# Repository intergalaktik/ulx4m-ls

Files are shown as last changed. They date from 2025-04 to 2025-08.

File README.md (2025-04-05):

<!--
SPDX-FileCopyrightText: 2016 2016 Goran Mahovlic, <goran.mahovlic@gmail.com> et al.

SPDX-License-Identifier: CERN-OHL-S-2.0
-->

# ULX4M-LS PCB

[ULX4M] = University digital Logic Learning Xtensible board release 4 Moduler successor of [ULX3S](http://radiona.org/ulx3s) = [University digital Logic](https://www.fer.unizg.hr/en/course/diglog) Learning
Xtensible board release 3 with SDRAM,
Successor of [ULX2S](http://github.com/emard/ulx2s).

### 3D preview

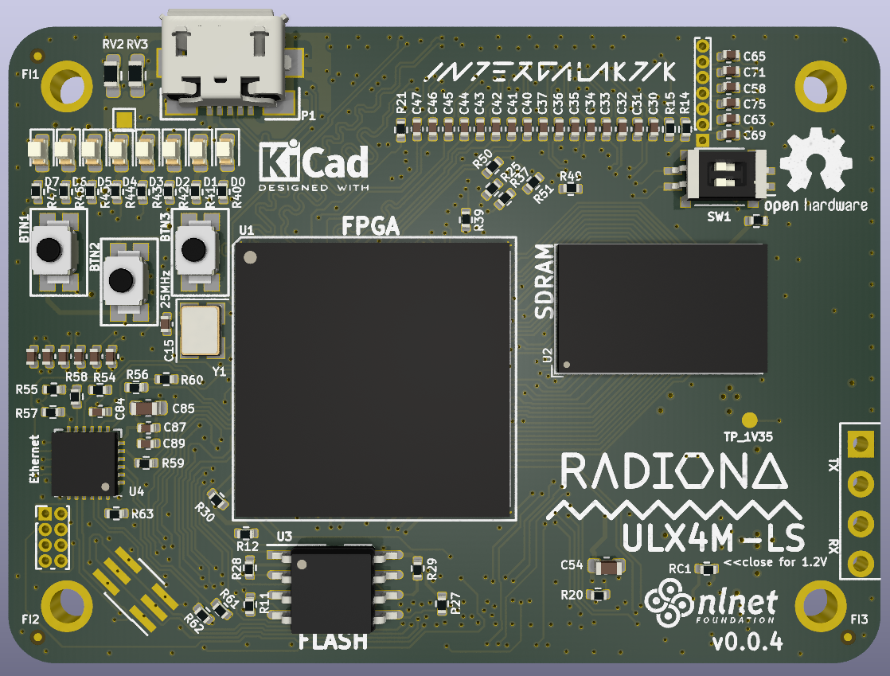
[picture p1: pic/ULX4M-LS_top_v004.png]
TOP

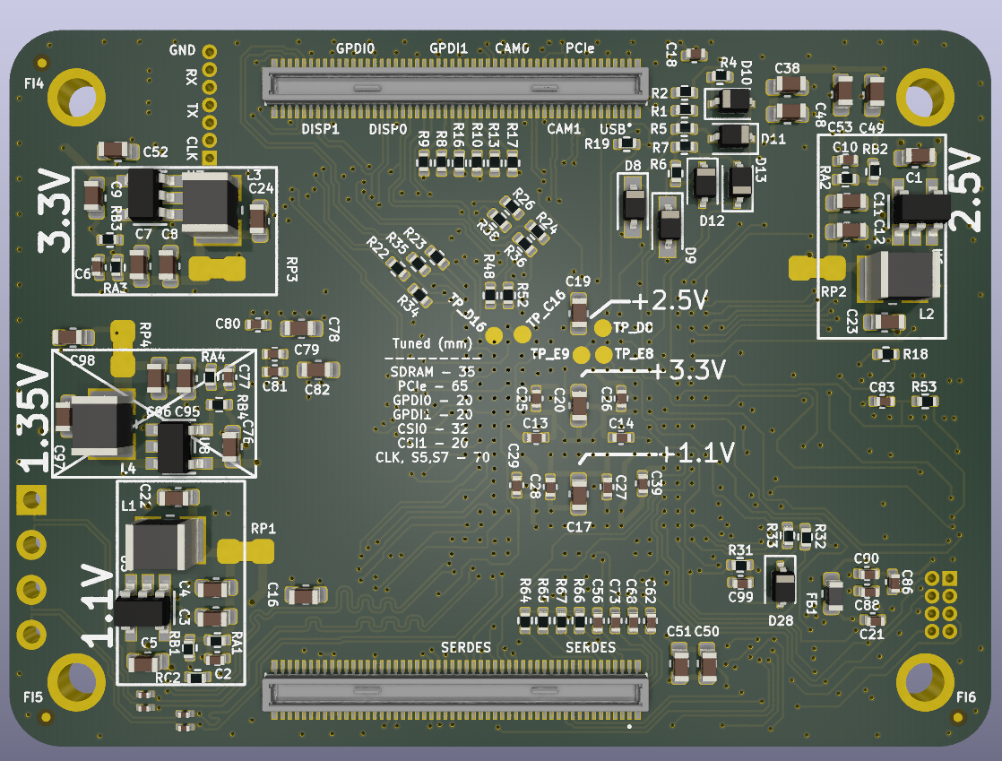
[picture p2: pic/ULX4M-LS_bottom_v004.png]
BOTTOM

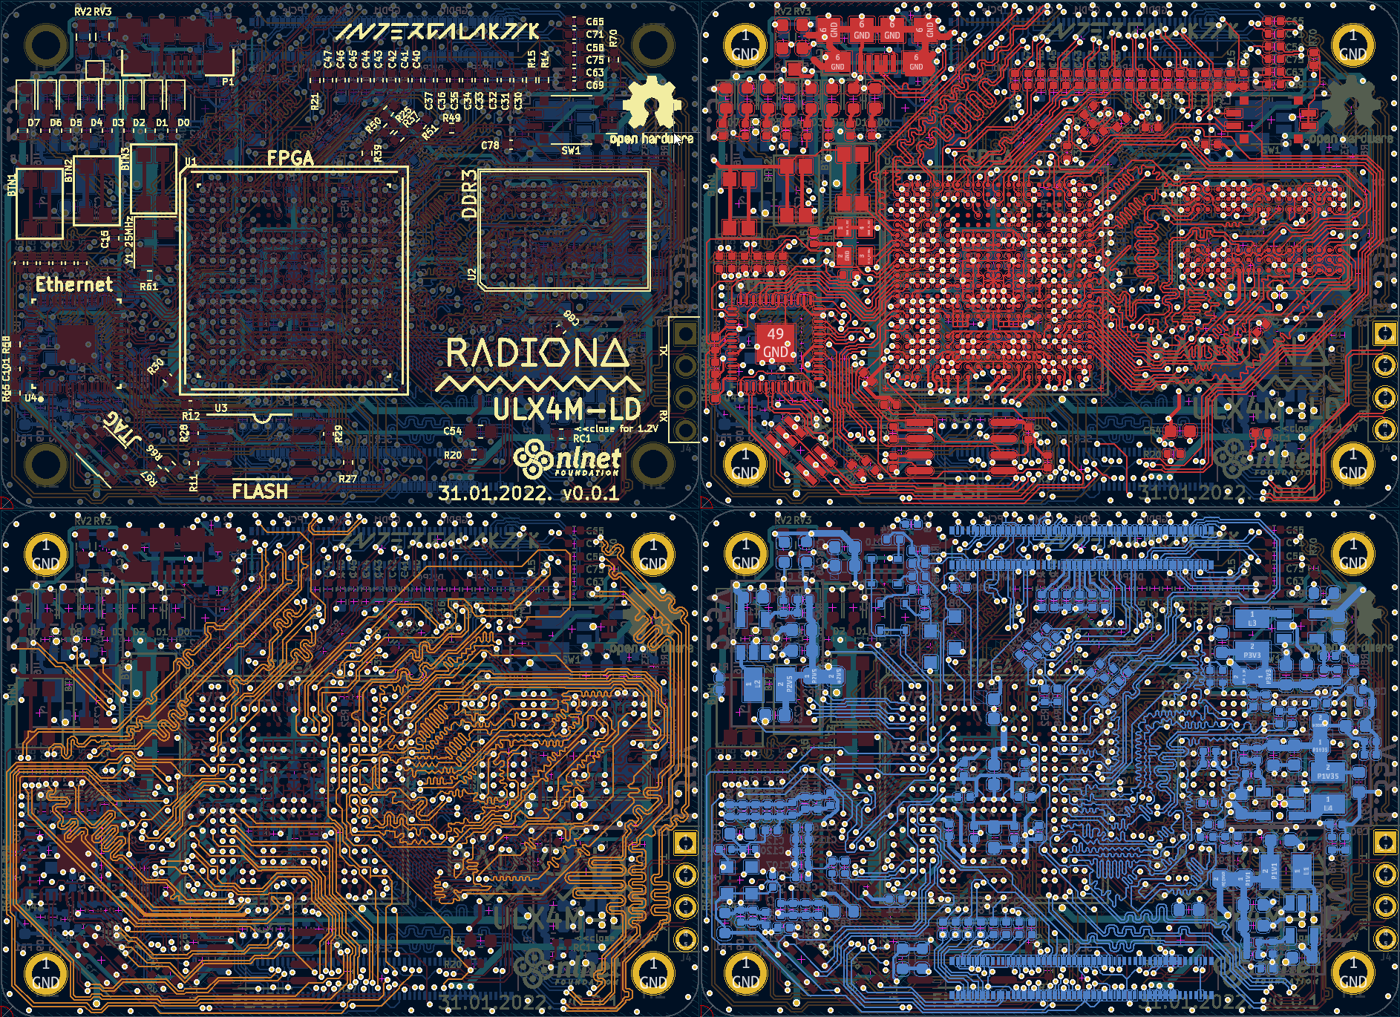
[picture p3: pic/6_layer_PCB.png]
Layers_v001


### Panel

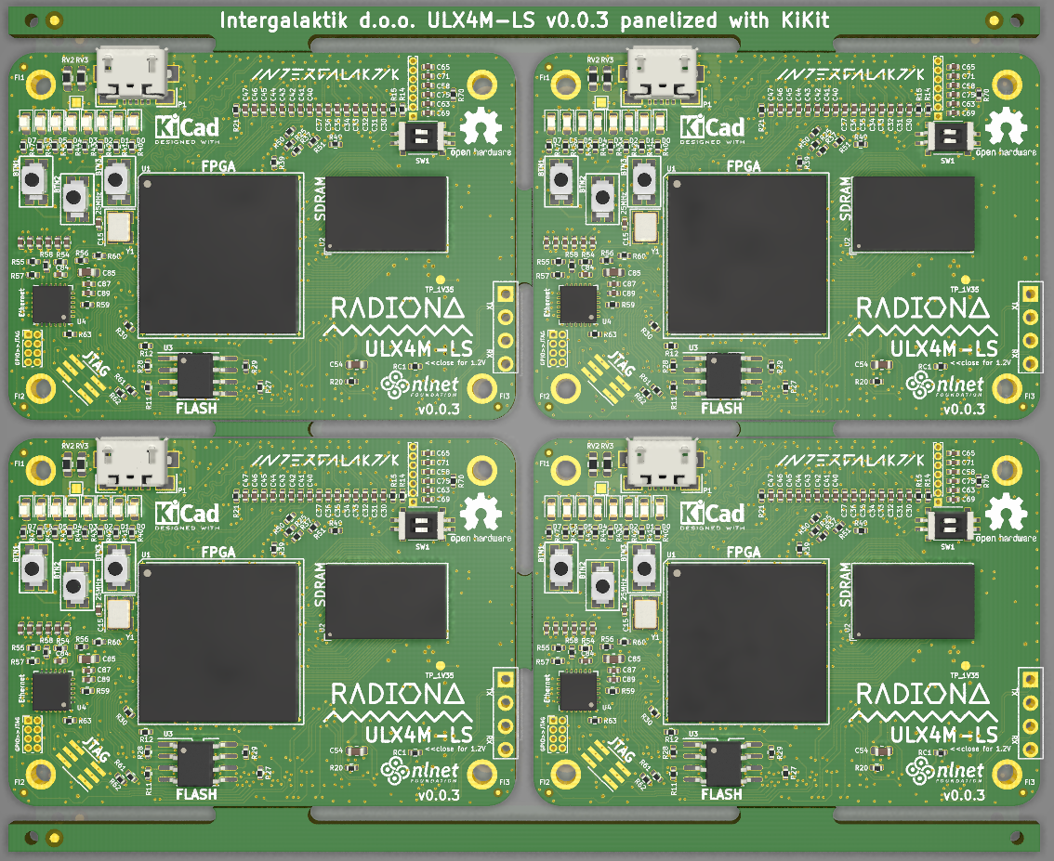
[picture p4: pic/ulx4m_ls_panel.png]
Panel


[Schematics](/doc/schematics.pdf) and PCB KiCAD 5 PCB editor:

    kicad ulx4m.pro

## Features

FPGA: Lattice ECP5 [LFE5U-12F-6BG381C](http://www.latticesemi.com/~/media/LatticeSemi/Documents/DataSheets/ECP5/FPGA-DS-02012.pdf?document_id=50461) (12/25/45/85K LUT)

### Main parts

LFE5U-12F-6BG381C

IS42S16160G-7BL 32 MB SDRAM 

W25Q128JVSIM NOR Flash spiFlash, 3V, 128M-bit, 4Kb Uniform Sector

Ethernet - LAN8720A

### Programming options

External JTAG programming connector

JTAG connected to GPIO (programming with FTDI or ESP32)

USB (bootloader)

### Periferals

- [x] 2 lane CSI camera port  CAM0 and CAM1

- [x] 2 lane DSI display port DISP0 (fake differential)

- [x] DISP0 pins connected to DISP1

- [x] * SerDes pair (TX/RX) connected to 2.0 header (radio experiments)

- [x] True differential GPDI video output

- [x] Fake differential GPDI video output

- [x] 4 bit SD card connection

- [x] * SerDes connected to PCIe 1x 

- [x] * 2x SerDes pairs connected over capacitors to connector

- [x] GPIOs

- [x] 3 Buttons

- [x] 2 DIP SW

- [x] 8 LEDs

* Only available if ECP5 SerDes chip is used

### ULX4M on TOFU carrier board

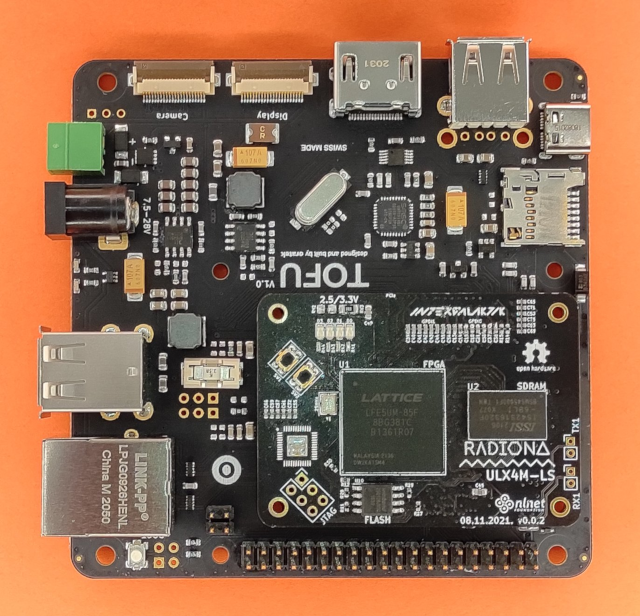
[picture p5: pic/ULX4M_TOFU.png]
TOFU


## References

https://github.com/gatecat/TrellisBoard

https://github.com/orangecrab-fpga/orangecrab-hardware

https://github.com/antmicro/ecp5-dc-scm

https://github.com/butterstick-fpga/butterstick-hardware

## Work on this board is financed by NLnet foundation

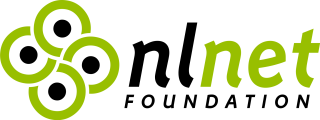
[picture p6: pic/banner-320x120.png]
NLnet


https://nlnet.nl/project/ULX3M/

## Check up our blogposts

https://intergalaktik.eu/news/ulx4s-v0-0-1

https://intergalaktik.eu/news/ulx4s-v0-0-2

https://intergalaktik.eu/news/blending-ulx4m-nlnet-funded-fpga-board

https://intergalaktik.eu/news/production-testing-automation-for-ulx3s

https://intergalaktik.eu/news/blending-ulx4m-ls-v002

## Contact us

Discord: https://discord.gg/qwMUk6W

Gitter: https://gitter.im/ulx3s/Lobby

Mail: warp@intergalaktik.eu

Twitter: https://twitter.com/intergalaktikEU

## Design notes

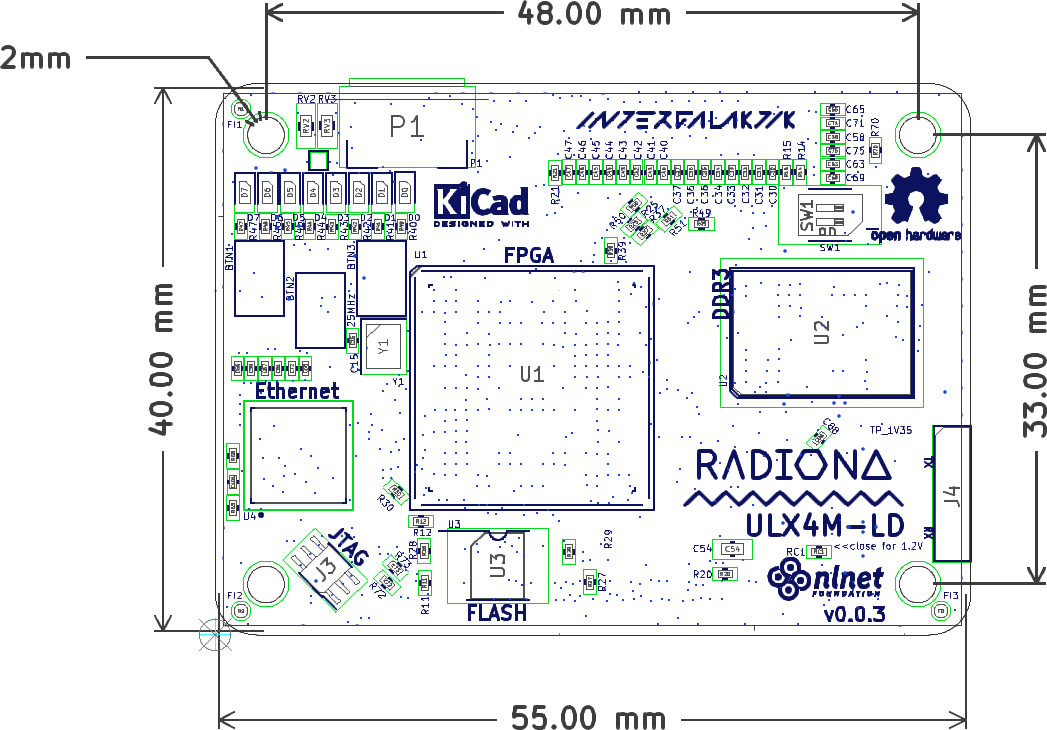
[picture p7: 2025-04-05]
pic/ulx4m_drawings.png

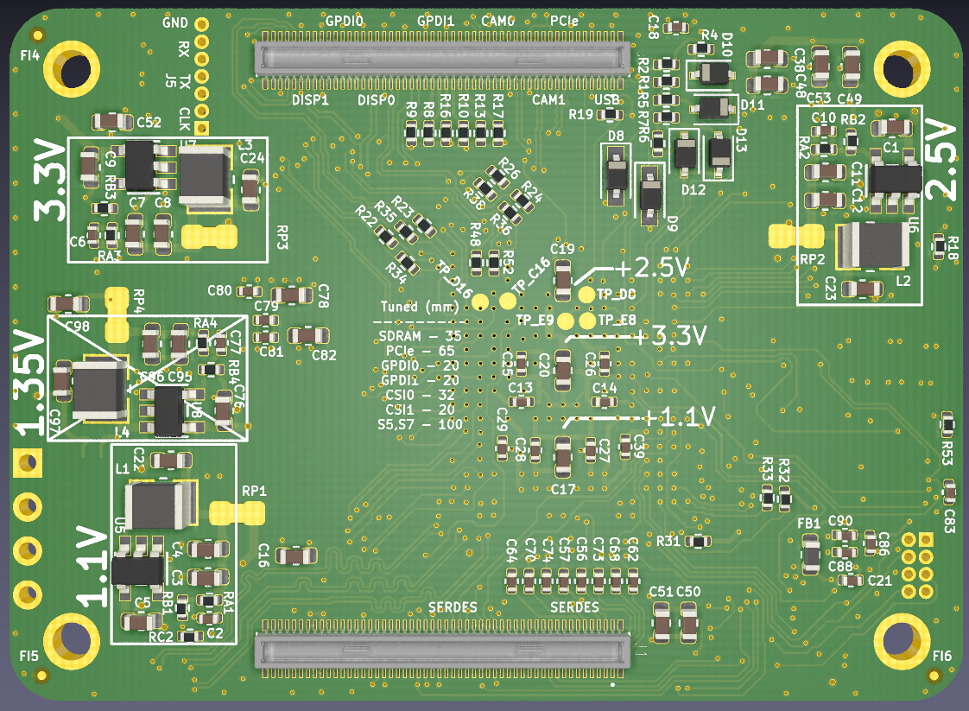
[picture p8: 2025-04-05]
pic/ULX4M-LS_bottom_v003.png

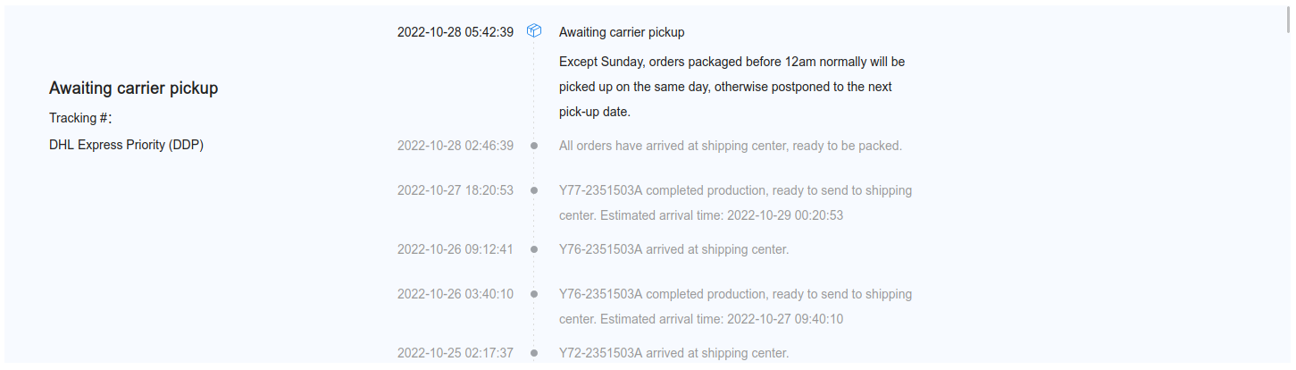
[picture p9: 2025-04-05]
pic/shipping.png

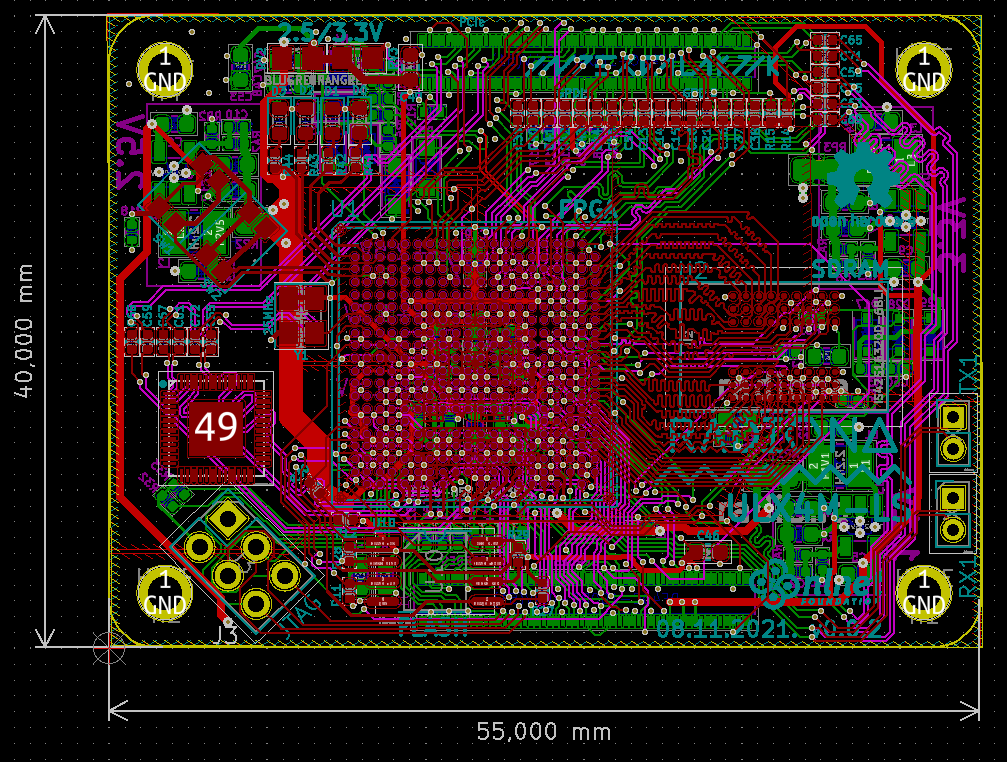
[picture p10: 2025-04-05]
pic/ULX4M_routed_V002.png

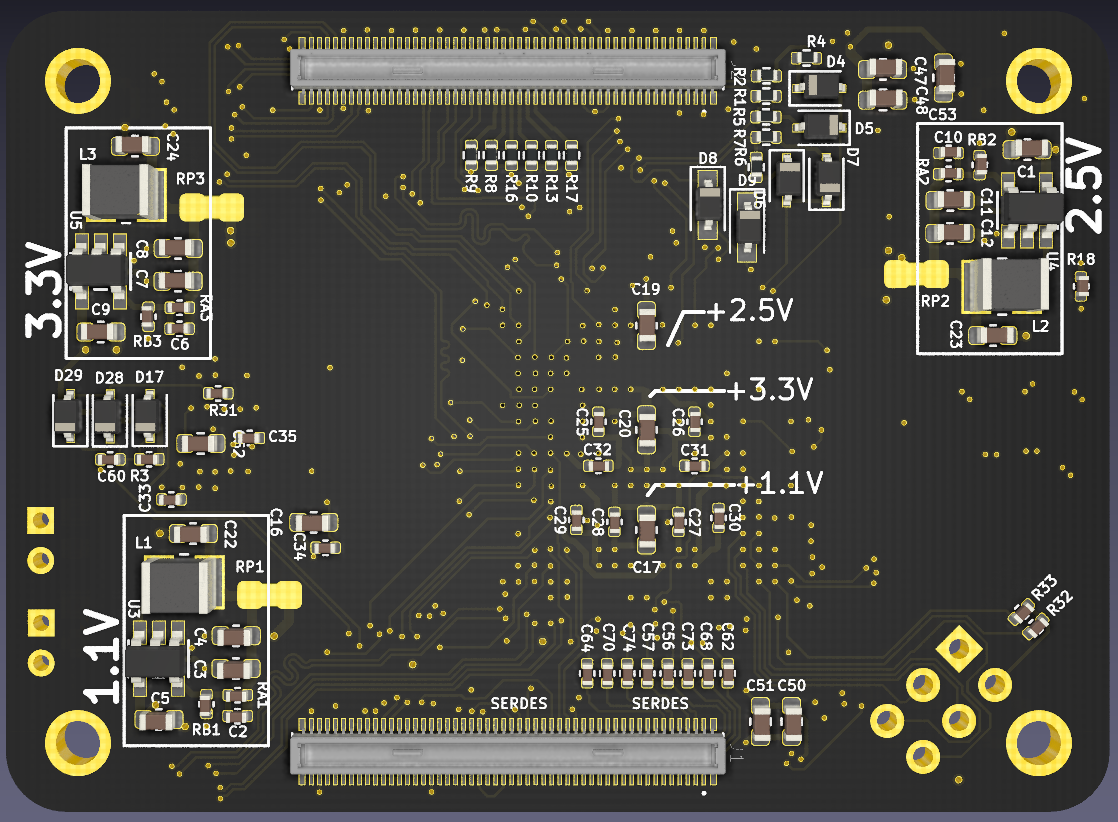
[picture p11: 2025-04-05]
pic/ULX4M_bottom_v002.png

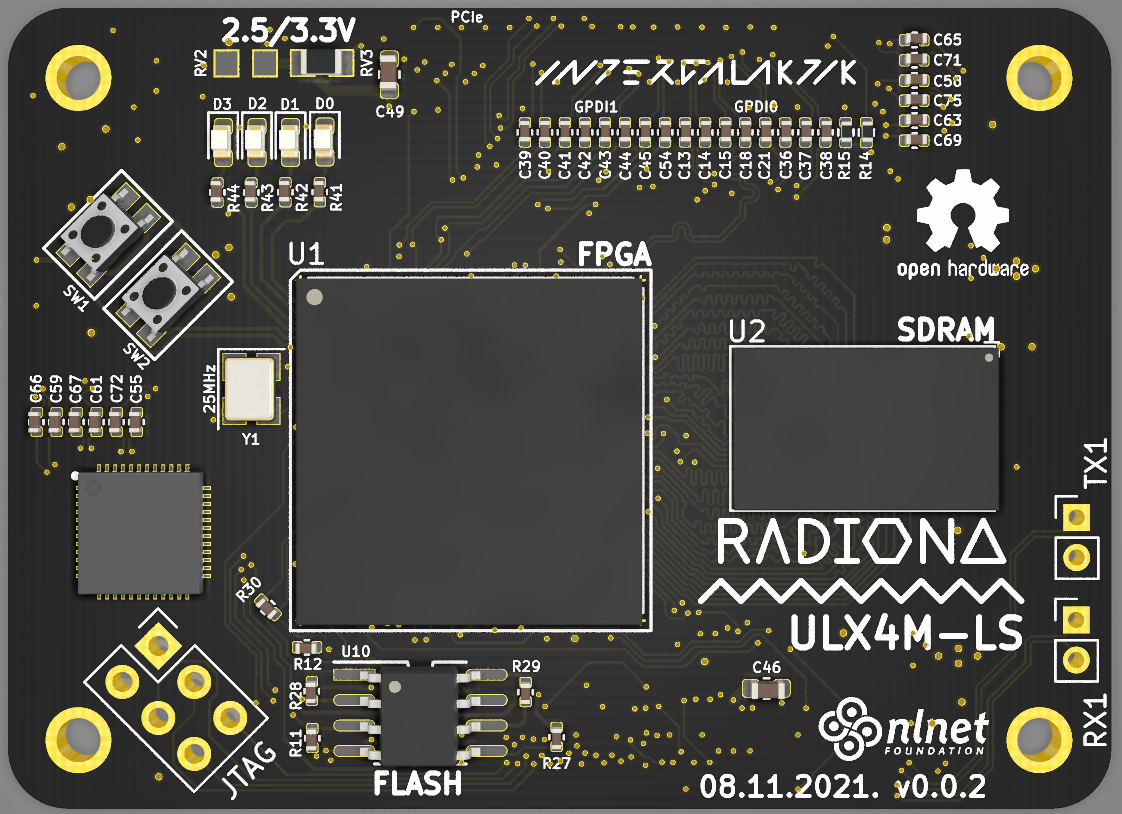
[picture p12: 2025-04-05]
pic/ULX4M_top_v002.png

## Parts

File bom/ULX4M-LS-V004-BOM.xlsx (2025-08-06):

Reference | Manufacturer Part Number | Manufacturer | Part Match | Description | Quantity | Selected Offers | Selected Offers (Distributor Link) | Packaging | Min | Mult | Total Quantity | Total Price | Selected Offers | Selected Offers (Distributor Link) | Arrow Electronics | Avnet | DigiKey | Future Electronics | Mouser | Newark | RS | Manufacturer Lifecycle | RoHS | REACH | Unit Price | Subtotal | Stock
C13, C14, C15, C18, C21, C25, C26, C27, C28, C29, C39, C55, C56, C58, C59, C61, C62, C63, C65, C66, C67, C68, C69, C71, C72, C73, C75, C79, C80, C81, C88 | GRM155R60J223KA01D | Murata | Exact | 0402 22 nF 6.3 V ±10% Tolerance X5R SMT Multilayer Ceramic Capacitor | 31 | Arrow Electronics GRM155R60J223KA01D (https://octopart.com/opatz8j6/a1) | https://octopart.com/opatz8j6/a1 | Cut Tape | 1 | 1 | 31 | 0.0403 | Arrow Electronics GRM155R60J223KA01D | https://octopart.com/opatz8j6/a1 | GRM155R60J223KA01D |  |  |  | 81-GRM155R60J223KA1D | 97AK4044 |  | Not Recommended for New Designs | Compliant | Yes | 0.00118 | 0.43701 | 369
R18, R21, R22, R23, R24, R25, R26, R34, R35, R36, R37, R38, R40, R41, R42, R43, R44, R45, R46, R47, R61, R62, R64, R65, R66, R67, R70 | AC0402JR-07300RL | Yageo | Exact | Res Thick Film 0402 300 Ohm 5% 0.063W(1/16W) ±100ppm/C Pad SMD Automotive T/R | 27 | Mouser 603-AC0402JR-07300RL (https://octopart.com/opatz8j6/a1) | https://octopart.com/opatz8j6/a1 | Tape & Reel | 1 |  | 27 | 0.189 | DigiKey YAG3540CT-ND | https://octopart.com/opatz8j6/a1 | AC0402JR-07300RL | 58AK8897 | YAG3540CT-ND |  | 603-AC0402JR-07300RL | 58AK8897 |  | Active | Compliant | Yes | 0.0047 | 9.87 | 16172
C30, C31, C32, C33, C34, C35, C36, C37, C40, C41, C42, C43, C44, C45, C46, C47, C83, C84, C90, C99 | GRM152R60J104KE19D | Murata | Exact | Ceramic Capacitor, Multilayer, Ceramic, 6.3V, 10% +Tol, 10% -Tol, X5R, 15% TC, 0.1uF, Surface Mount, 0402 | 20 | Arrow Electronics GRM152R60J104KE19D (https://octopart.com/opatz8j6/a1) | https://octopart.com/opatz8j6/a1 | Cut Tape | 1 | 1 | 20 | 0.21 | Arrow Electronics GRM152R60J104KE19D | https://octopart.com/opatz8j6/a1 | GRM152R60J104KE19D |  | 490-14871-1-ND |  | 81-GRM152R60J104KE9D |  |  | Not Recommended for New Designs | Compliant | Yes | 0.00783 | 16.45 | 41966
R5, R7, R8, R9, R11, R12, R16, R17, R27, R28, R31, R32, R33, RA1, RA2, RA3 | AC0402JR-7W15KL | Yageo | Exact | Chip Resistor Automotive Grade Thick Film 0402 15kOhm 5% Paper T/R | 16 | Mouser 603-AC0402JR-7W15KL (https://octopart.com/opatz8j6/a1) | https://octopart.com/opatz8j6/a1 | Tape & Reel | 1 |  | 16 | 0.24 | Mouser 603-AC0402JR-7W15KL | https://octopart.com/opatz8j6/a1 |  |  |  |  | 603-AC0402JR-7W15KL |  |  | Active | Compliant | Yes | 0.00729 | 12.39 | 9990
C16, C17, C19, C20, C22, C23, C24, C38, C54, C78, C85 | GRM185R60J225KE26J | Murata | Exact | Ceramic Capacitor, Multilayer, Ceramic, 6.3V, 10% +Tol, 10% -Tol, X5R, 15% TC, 2.2uF, Surface Mount, 0603 | 11 | Mouser 81-GRM185R60J225KE6J (https://octopart.com/opatz8j6/a1) | https://octopart.com/opatz8j6/a1 | Tape & Reel | 1 |  | 11 | 1.35 | DigiKey 490-6371-1-ND | https://octopart.com/opatz8j6/a1 |  |  | 490-6371-1-ND |  | 81-GRM185R60J225KE6J |  |  | Not Recommended for New Designs | Compliant | Yes | 0.03944 | 43.38 | 30510
C1, C3, C4, C5, C7, C8, C9, C11, C12 | GRM188R60J226MEA0J | Murata | Exact | 0603 6.3 V 22 uF ±20% Tolerance X5R SMT Multilayer Ceramic Chip Capacitor | 9 | Mouser 81-GRM188R60J226ME0J (https://octopart.com/opatz8j6/a1) | https://octopart.com/opatz8j6/a1 | Tape & Reel | 1 |  | 10 | 0.91 | LCSC C426040 | https://octopart.com/opatz8j6/a1 | GRM188R60J226MEA0J | GRM188R60J226MEA0J | 490-GRM188R60J226MEA0JCT-ND |  | 81-GRM188R60J226ME0J | 66AJ7192 | 2478053 | Active | Compliant | Yes | 0.0129 | 15.48 | 6180
R10, R13, R14, R15, R19, R20, R30, RB2 | AC0402JR-074K7L | Yageo | Exact | SMD Chip Resistor 4.7 Kohm ½ 5% 63 Mw 0402 [1005 Metric] Thick Film General Purpose | 8 | Avnet 49AK0473 (https://octopart.com/opatz8j6/a1) | https://octopart.com/opatz8j6/a1 |  | 1 | 1 | 8 | 0.04 | Avnet 49AK0473 | https://octopart.com/opatz8j6/a1 | AC0402JR-074K7L | 49AK0473 | 311-4.7KLBCT-ND |  | 603-AC0402JR-074K7L | 49AK0473 | 1978008 | Active | Compliant | Yes | 0.00456 | 4.56 | 8750
C48, C49, C50, C51, C52, C53, C82 | GCM188R72A223KA37J | Murata | Exact | Multilayer Ceramic Capacitor 0.022 Uf 100 V ½ 10% X7R 0603 [1608 Metric] | 7 | Arrow Electronics GCM188R72A223KA37J (https://octopart.com/opatz8j6/a1) | https://octopart.com/opatz8j6/a1 | Cut Tape | 1 | 1 | 10 | 0.079 | Arrow Electronics GCM188R72A223KA37J | https://octopart.com/opatz8j6/a1 | GCM188R72A223KA37J | GCM188R72A223KA37J | 490-17777-1-ND | 5139968 | 81-GCM188R72A223KA7J | 66AJ7159 |  | Active | Compliant | Yes | 0.00683 | 4.1 | 29893
R1, R2, R54, R56, R58, R59, R60 | AC0402JR-0727RL | Yageo | Exact | AC Series 0402 27 Ohm ±5% 0.063 W ±200 ppm/°C Thick Film Chip Resistor | 7 | Mouser 603-AC0402JR-0727RL (https://octopart.com/opatz8j6/a1) | https://octopart.com/opatz8j6/a1 | Tape & Reel | 1 |  | 10 | 0.07 | DigiKey 13-AC0402JR-0727RLCT-ND | https://octopart.com/opatz8j6/a1 |  | 58AK8894 | 13-AC0402JR-0727RLCT-ND |  | 603-AC0402JR-0727RL | 58AK8894 |  | Active | Compliant | Yes | 0.0056 | 1.12 | 52516
D10, D11, D12, D13, D15, D28 | 1N914BWS | onsemi | Exact | Diode Ultra Fast Recovery Rectifier 75V 0.15A 2-Pin SOD-323F T/R | 6 | Newark 18X9969 (https://octopart.com/opatz8j6/a1) | https://octopart.com/opatz8j6/a1 | Cut Tape | 1 | 1 | 6 | 0.138 | TME 1N914BWS | https://octopart.com/opatz8j6/a1 | 1N914BWS | 1N914BWS | 1N914BWSCT-ND | 4190584 | 512-1N914BWS | 18X9969 |  | Active | Compliant | Yes | 0.0325 | 16.25 | 2230
R39, R48, R49, R50, R51, R52 | AC0402FR-0771R5L | Yageo | Exact | Chip Resistor Automotive Grade Thick Film 0402 71.5Ohm 1% Paper T/R | 6 | Mouser 603-AC0402FR-0771R5L (https://octopart.com/opatz8j6/a1) | https://octopart.com/opatz8j6/a1 | Tape & Reel | 1 |  | 10 | 0.14 | Mouser 603-AC0402FR-0771R5L | https://octopart.com/opatz8j6/a1 |  |  | 13-AC0402FR-0771R5LCT-ND |  | 603-AC0402FR-0771R5L |  |  | Active | Compliant | Yes | 0.0082 | 6.56 | 29460
R4, R6, R29, R55, R57 | AC0402JR-7W1KL | Yageo | Exact | Res Thick Film 0402 1K Ohm 5% 0.125W(1/8W) ±100ppm/°C Pad SMD T/R Automotive AEC-Q200 | 5 | Mouser 603-AC0402JR-7W1KL (https://octopart.com/opatz8j6/a1) | https://octopart.com/opatz8j6/a1 | Tape & Reel | 1 |  | 10 | 0.09 | DigiKey 13-AC0402JR-7W1KLCT-ND | https://octopart.com/opatz8j6/a1 |  |  | 13-AC0402JR-7W1KLCT-ND |  | 603-AC0402JR-7W1KL |  |  | Active | Compliant | Yes | 0.0061 | 3.05 | 10054
L1, L2, L3 | DFE322520F-2R2M=P2 | Murata | Exact | Inductor Chip Shielded Wirewound 2.2uH 20% 1MHz Metal Alloy 3.3A 1210 Emboss T/R | 3 | 81-DFE322520F2R2M=P2 (https://octopart.com/opatz8j6/a1) | https://octopart.com/opatz8j6/a1 | Tape & Reel | 1 |  | 3
U5, U6, U7 | TLV62569DBVR | Texas Instruments | Exact | Conv DC-DC 2.5V to 5.5V Synchronous Step Down Single-Out 0.6V to 5.5V 2A 5-Pin SOT-23 T/R | 3 | Arrow Electronics TLV62569DBVR (https://octopart.com/opatz8j6/a1) | https://octopart.com/opatz8j6/a1 | Cut Tape | 1 | 1 | 3 | 0.66 | DigiKey 296-47360-1-ND | https://octopart.com/opatz8j6/a1 | TLV62569DBVR |  | 296-47360-1-ND |  | 595-TLV62569DBVR |  |  | Active | Compliant |  | 0.09528 | 38.11 | 12574
BTN1, BTN2, BTN3 | EVPAA302K | Panasonic | Exact | Switch Tactile N.O. SPST Rectangular Button J-Bend 0.02A 15VDC 1.6N SMD Embossed T/R | 3 | Mouser 667-EVP-AA302K (https://octopart.com/opatz8j6/a1) | https://octopart.com/opatz8j6/a1 | Tape & Reel | 1 |  | 3 | 2.25 | Newark 47AC4938 | https://octopart.com/opatz8j6/a1 |  |  |  |  |  | 47AC4938 |  | Active | Compliant | Yes | 0.36805 | 110.41 | 422
C2, C6, C10 | 04026C101KAT2A | KYOCERA AVX | Exact | SMD Multilayer Ceramic Capacitor, 100 pF, 6.3 V, 0402 [1005 Metric], ï¿½ 10%, X7R | 3 | Mouser 581-04026C101KAT2A (https://octopart.com/opatz8j6/a1) | https://octopart.com/opatz8j6/a1 | Tape & Reel | 1 |  | 3 | 0.63 | Mouser 581-04026C101KAT2A | https://octopart.com/opatz8j6/a1 |  | KGM05AR70J101KH |  |  | 581-04026C101KAT2A |  |  | Active | Compliant | Yes | 0.06468 | 25.87 | 25210
D0, D4 | LTST-C190KRKT | Lite-On | Exact | LED LTST-C190KRKT; SMD 0603; czerwona 631-639nm; 99mcd /20mA; water clear | 2 | DigiKey 160-1436-1-ND (https://octopart.com/opatz8j6/a1) | https://octopart.com/opatz8j6/a1 | Cut Tape | 1 |  | 2 | 0.28 | DigiKey 160-1436-1-ND | https://octopart.com/opatz8j6/a1 | LTST-C190KRKT | LTST-C190KRKT | 160-1436-1-ND | 5050042 |  |  | 6920981 | Active | Compliant | Yes | 0.05912 | 11.82 | 12041
D3, D7 | LTST-C190TBKT | Lite-On | Exact | LTST-C190TBKT Lite-on Standard Led Blue 470NM 3.3V SMD 0603 Rohs | 2 | DigiKey 160-1646-1-ND (https://octopart.com/opatz8j6/a1) | https://octopart.com/opatz8j6/a1 | Cut Tape | 1 |  | 2 | 0.68 | TME LTST-C190TBKT | https://octopart.com/opatz8j6/a1 |  |  | 160-1646-1-ND | 4438875 |  |  | 6920994 | Active | Compliant | Yes | 0.0734 | 14.68 | 18883
D1, D5 | LTST-C190KAKT | Lite-On | Exact | Single Color LED, Red Orange, Water Clear, 1.06mm | 2 | DigiKey 160-1433-1-ND (https://octopart.com/opatz8j6/a1) | https://octopart.com/opatz8j6/a1 | Cut Tape | 1 |  | 2 | 0.4 | DigiKey 160-1433-1-ND | https://octopart.com/opatz8j6/a1 | LTST-C190KAKT |  | 160-1433-1-ND |  |  |  |  | Active | Compliant | Yes | 0.125 | 25 | 47325
D2, D6 | LTST-C191KGKT | Lite-On | Exact | Single Color LED, Ultra Bright Green, Water Clear, 1.1mm | 2 | DigiKey 160-1446-1-ND (https://octopart.com/opatz8j6/a1) | https://octopart.com/opatz8j6/a1 | Cut Tape | 1 |  | 2 | 0.3 | TME LTST-C191KGKT | https://octopart.com/opatz8j6/a1 | LTST-C191KGKT |  | 160-1446-1-ND | 3023739 |  |  | 6921010 | Active | Compliant | Yes | 0.0433 | 8.66 | 6081
D8, D9 | BZT52C3V6S-TP | MCC | Exact | Zener Diode, 3.6V V(Z), 5.56%, 0.2W, Silicon, Unidirectional | 2 | Mouser 833-BZT52C3V6S-TP (https://octopart.com/opatz8j6/a1) | https://octopart.com/opatz8j6/a1 | Tape & Reel | 1 |  | 2 | 0.6 | Mouser 833-BZT52C3V6S-TP | https://octopart.com/opatz8j6/a1 | BZT52C3V6S-TP |  | BZT52C3V6S-TPMSCT-ND |  | 833-BZT52C3V6S-TP |  |  | Active | Compliant | Yes | 0.06924 | 13.85 | 1313
Y1 | ECS-2333-250-BN-TR | ECS International | Exact | Series ESC-2333 3.3V 15pF -40°C~+85°C ±50ppm SMD/SMT Standard Clock Oscillators | 2 | Mouser 520-2333-250-BNT (https://octopart.com/opatz8j6/a1) | https://octopart.com/opatz8j6/a1 | Tape & Reel | 1 |  | 2 | 1.64 | Mouser 520-2333-250-BNT | https://octopart.com/opatz8j6/a1 | ECS-2333-250-BN-TR | ECS-2333-250-BN-TR | XC3035CT-ND |  | 520-2333-250-BNT | 79AK9042 |  | Active | Compliant | Yes | 0.61857 | 123.71 | 2724
J1, J2 | DF40C-100DP-0.4V(51) | HIROSE ELECTRIC | Exact | Conn Board to Board HDR 100 POS 0.4mm Solder ST Top Entry SMD T/R | 2 | Mouser 798-DF40C100DP0.4V51 (https://octopart.com/opatz8j6/a1) | https://octopart.com/opatz8j6/a1 | Tape & Reel | 1 |  | 2 | 3.24 | TME DF40C-100DP-04V-51 | https://octopart.com/opatz8j6/a1 |  | DF40C-100DP-0.4V(51) | H11614CT-ND |  | 798-DF40C100DP0.4V51 |  |  | Active | Compliant | Yes | 1.07 | 214 | 2183
C86, C89 | GRM155R60J103KA01D | Murata | Exact | SMD Multilayer Ceramic Capacitor, 0.01 ï¿½F, 6.3 V, 0402 [1005 Metric], ï¿½ 10%, X5R | 2 | Newark 97AK4032 (https://octopart.com/opatz8j6/a1) | https://octopart.com/opatz8j6/a1 | Cut Tape | 10 | 10 | 10 | 0.1 | DigiKey 490-6286-1-ND | https://octopart.com/opatz8j6/a1 | GRM155R60J103KA01D |  | 490-6286-1-ND |  | 81-GRM155R60J103KA1D | 97AK4032 |  | Not Recommended for New Designs | Compliant | Yes | 0.00802 | 11.23 | 58257
R53, R63 | RT0402BRD0712K1L | Yageo | Selected | SMD Chip Resistor, 12.1 kohm, ï¿½ 0.1%, 63 mW, 0402 [1005 Metric], Thin Film | 2 | Arrow Electronics RT0402BRD0712K1L (https://octopart.com/opatz8j6/a1) | https://octopart.com/opatz8j6/a1 | Cut Tape | 1 | 1 | 2 | 0.192
U1 | LFE5U-12F-6BG381C | Lattice Semiconductor | Selected | FPGA LatticeECP5 Family 12000 Cells 40nm Technology 1.1V 381-Pin CABGA Tray | 1 | Mouser 842-LFE5U12F6BG381C (https://octopart.com/opatz8j6/a1) | https://octopart.com/opatz8j6/a1 |  | 1 |  | 1 | 19.25 | Mouser 842-LFE5UM85F8BG381I | https://octopart.com/opatz8j6/a1 | LFE5UM-85F-8BG381I |  | LFE5UM-85F-8BG381I-ND |  | 842-LFE5UM85F8BG381I |  |  | Active | Compliant | Yes | 79.7 | 7970.38 | 208
U2 | IS42S16160J-6BLI | ISSI | Selected | DRAM, SDRAM, 256 Mbit, 16M x 16bit, 166 MHz, 54 Pins, TFBGA | 1 | Mouser 870-42S16160J6BLI (https://octopart.com/opatz8j6/a1) | https://octopart.com/opatz8j6/a1 | Tray | 1 |  | 1 | 4.01 | Mouser 913-4C51216D3LB12BCN | https://octopart.com/opatz8j6/a1 |  | AS4C512M16D3LB-12BCN |  |  | 913-4C51216D3LB12BCN | 82AK3816 |  | Active | Compliant | Yes | 21.86 | 2185.5 | 792
U3 | IS25LP128F-JBLE | ISSI | Exact | NOR Flash Serial (SPI, Dual SPI, Quad SPI) 2.5V/3V/3.3V 128M-bit 16M x 8 8ns 8-Pin SOIC | 1 | Arrow Electronics IS25LP128F-JBLE (https://octopart.com/opatz8j6/a1) | https://octopart.com/opatz8j6/a1 |  | 1 | 1 | 1 | 1.79 | Arrow Electronics IS25LP128F-JBLE | https://octopart.com/opatz8j6/a1 | IS25LP128F-JBLE | 38AC3510 |  |  | 870-IS25LP128F-JBLE |  |  | Active | Compliant | Yes | 1.47 | 146.85 | 3240
U4 | LAN8720AI-CP-TR-ABC | Microchip | Selected | Small Footprint MII/RMII 10/100 Ethernet Transceiver with flexPWR Technology | 1 | Mouser 579-LAN8720AICPTRABC (https://octopart.com/opatz8j6/a1) | https://octopart.com/opatz8j6/a1 | Tape & Reel | 1 |  | 1 | 1.28 | LCSC C514073 | https://octopart.com/opatz8j6/a1 | KSZ9031RNXCA-TR |  | KSZ9031RNXCA-CT-ND | 7025411 | 998-KSZ9031RNXCATR |  |  | Active | Compliant |  | 3.18 | 41.36 | 13
SW1 | CVS-02TB | Nidec Copal | Exact | Switch DIP OFF ON SPST 2 Raised Slide 0.025A 24VDC Gull Wing SMD T/R | 1 | Mouser 229-CVS-02TB (https://octopart.com/opatz8j6/a1) | https://octopart.com/opatz8j6/a1 | Tape & Reel | 1 |  | 1 | 3.05 | Mouser 229-CVS-02TB | https://octopart.com/opatz8j6/a1 |  |  | 563-1193-1-ND |  | 229-CVS-02TB | 56AC5330 |  | Active | Compliant | Yes | 1.93 | 193.13 | 359
P1 | 10118192-0001LF | Amphenol Communications Solutions | Exact | Usb Connector, 5 Contact(S), Female, Right Angle, Surface Mount Terminal, Locking, Receptacle | 1 | Arrow Electronics 10118192-0001LF (https://octopart.com/opatz8j6/a1) | https://octopart.com/opatz8j6/a1 |  | 1 | 1 | 1 | 0.2901 | Arrow Electronics 10118192-0001LF | https://octopart.com/opatz8j6/a1 | 10118192-0001LF | 67T2258 | 609-4613-1-ND |  | 649-10118192-0001LF | 67T2258 | 1822981 | Active | Compliant | Yes | 0.19204 | 19.2 | 1093
RB3 | AC0402JR-073K3L | Yageo | Exact | Res Thick Film 0402 3.3K Ohm 5% 0.063W(1/16W) ±100ppm/C Pad SMD T/R Automotive AEC-Q200 | 1 | Arrow Electronics AC0402JR-073K3L (https://octopart.com/opatz8j6/a1) | https://octopart.com/opatz8j6/a1 | Cut Tape | 1 | 1 | 1 | 0.016 | Arrow Electronics AC0402JR-073K3L | https://octopart.com/opatz8j6/a1 | AC0402JR-073K3L | 59AK5032 | YAG3544CT-ND | 5110652 | 603-AC0402JR-073K3L | 59AK5032 |  | Active | Compliant | Yes | 0.00246 | 0.24597 | 15198
RB1 | AC0402JR-0718KL | Yageo | Exact | Res Thick Film 0402 18K Ohm 5% 0.063W(1/16W) ±100ppm/C Pad SMD Automotive T/R | 1 | Mouser 603-AC0402JR-0718KL (https://octopart.com/opatz8j6/a1) | https://octopart.com/opatz8j6/a1 | Tape & Reel | 1 |  | 10 | 0.07 | Mouser 603-AC0402JR-0718KL | https://octopart.com/opatz8j6/a1 | AC0402JR-0718KL |  | 13-AC0402JR-0718KLCT-ND |  | 603-AC0402JR-0718KL |  |  | Active | Compliant | Yes | 0.00547 | 0.5466 | 20000
RC2 | AC0402JR-0791KL | Yageo | Exact | Chip Resistor Automotive Grade Thick Film 0402 91kOhm 5% Paper T/R | 1 | Newark 59AK3056 (https://octopart.com/opatz8j6/a1) | https://octopart.com/opatz8j6/a1 | Cut Tape | 1 | 1 | 1 | 0.001 | Newark 59AK3056 | https://octopart.com/opatz8j6/a1 |  | 59AK3056 |  |  | 603-AC0402JR-0791KL | 59AK3056 |  | Active | Compliant | Yes | 0.00091 | 0.0911 | 20000
RV3 | AF0603JR-070RL | Yageo | Exact | Zero Ohm Resistor Jumper 0603 [1608 Metric] Thick Film 100 Mw 1 A Surface Mount | 1 | Newark 49AK6954 (https://octopart.com/opatz8j6/a1) | https://octopart.com/opatz8j6/a1 | Cut Tape | 1 | 1 | 1 | 0.005 | Newark 49AK6954 | https://octopart.com/opatz8j6/a1 | AF0603JR-070RL | 49AK6954 | 13-AF0603JR-070RLCT-ND |  | 603-AF0603JR-070RL | 49AK6954 |  | Active | Compliant | Yes | 0.00456 | 0.4555 | 4854
FB1 | BLM18PG121SN1D | Murata | Selected | Ferrite Beads Multi-Layer 120Ohm 25% 100MHz 2A 50mOhm DCR 0603 Paper T/R | 1 | Mouser 81-BLM18PG121SN1D (https://octopart.com/opatz8j6/a1) | https://octopart.com/opatz8j6/a1 | Tape & Reel | 1 |  | 1 | 0.1
C87 | GRM155R71H471KA01J | Murata | Selected | Cap Ceramic 470pF 50V X7R 10% Pad SMD 0402 125C T/R | 1 | Arrow Electronics GRM155R71H471KA01J (https://octopart.com/opatz8j6/a1) | https://octopart.com/opatz8j6/a1 | Cut Tape | 1 | 1 | 1 | 0.016

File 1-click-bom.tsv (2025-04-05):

References | Qty | Description | Manufacturer | MPN | Manufacturer | MPN | Manufacturer | MPN | Manufacturer | MPN | Digikey | Mouser | RS | Newark | Farnell | LCSC | JLC Assembly
C2, C6, C10 | 3 | 100pF |  | 04026C101KAT2A | AVX | 04026C101KAT2A |  |  |  |  | 478-12647-6-ND | 58104026C101KAT2A
C25, C26, C27, C28, C29, C30, C31, C32, C33, C34, C35, C55, C56, C57, C58, C59, C61, C62, C63, C64, C65, C66, C67, C68, C69, C70, C71, C72, C73, C74, C75 | 31 | 22nF |  | 04023D223KAT2A | KYOCERA AVX | 04023D223KAT2A |  |  |  |  | 478-10083-1-ND | 58104023D223KAT2A |  |  | 3288826
C48, C49, C50, C51, C52, C53 | 6 | 22nF |  | 06033D223KAT2A | KYOCERA AVX | 06033D223KAT2A |  |  |  |  | 478-06033D223KAT2ATR-ND | 58106033D223KAT2A
C13, C14, C15, C18, C21, C36, C37, C38, C39, C40, C41, C42, C43, C44, C45, C54 | 16 | 100n |  | 0402YD104KAT2A | AVX | 0402YD104KAT2A |  |  |  |  | 478-1126-1-ND | 5810402YD104K | 6983197 |  | 1327666
C60 | 1 | 220nF |  | CGB2T3X5R0J224M022BB | TDK | CGB2T3X5R0J224M022BB |  |  |  |  | 445-15613-1-ND | 810CGB2T3X5R0J224MB
C16, C17, C19, C20, C22, C23, C24, C46, C47 | 9 | 2.2uF |  | 06033D225KAT2A | AVX | 06033D225KAT2A |  |  |  |  |  | 58106033D225KAT2A
C1, C3, C4, C5, C7, C8, C9, C11, C12 | 9 | 22uF |  | C0603C226M9PACTU | KEMET | C0603C226M9PACTU |  |  |  |  |  | 80C0603C226M9PACTU |  |  | 3754565
RV3 | 1 | 0 |  | RC0805JR-070RL | Yageo | RC0805JR-070RL | Yageo | RC0805JR-070RP | Vishay | RCG08050000Z0EA | 311-0.0ARCT-ND | 603RC0805JR070RL | 1995753 |  | 1799478
R1, R2 | 2 | 27 |  | RC0402FR-0727RL | Yageo | RC0402FR-0727RL |  |  |  |  | YAG3086DKR-ND | 603RC0402FR0727RL |  |  | 9239049
R18 | 1 | 130 |  | RC0402FR-07130RL | Yageo | RC0402FR-07130RL |  |  |  |  | 311-130LRDKR-ND | 603RC0402FR07130RL |  |  | 3495526
R41, R42, R43, R44 | 4 | 549 |  | RT0402BRD07549RL | Yageo | RT0402BRD07549RL |  |  |  |  | YAG4280DKR-ND | 603RT0402BRD07549RL
R29, R4, R6 | 3 | 1.1k |  | RC0402JR-071K1L | Yageo | RC0402JR-071K1L |  |  |  |  | 311-1.1KJRCT-ND | 603RC0402JR071K1L
RB3 | 1 | 3.3k |  | RC0402FR-073K3L | Yageo | RC0402FR-073K3L |  |  |  |  | 311-3.30KLRCT-ND | 603RC0402FR073K3L | 1987781 |  | 2693607
R3, R30, RB2, R10, R13, R14, R15, R19, R20 | 9 | 4.7k |  | RC0402JR-074K7L | Yageo | RC0402JR-074K7L |  |  |  |  | 311-4.7KJRCT-ND | 603RC0402JR074K7L | 1987981 |  | 9232842
R11, R12, R27, R28 | 4 | 10k |  | CRCW040210K0FKTD | Vishay | CRCW040210K0FKTD |  |  |  |  | 541-2955-6-ND | 71CRCW040210K |  |  | 1652741RL
R31, R32, R33, RA1, RA2, RA3, R5, R7 | 8 | 15k |  | RMCF0402FT15K0 | Stackpole Electronics | RMCF0402FT15K0 |  |  |  |  | RMCF0402FT15K0CT-ND
RB1 | 1 | 18k |  | RC0402FR-0718KL | Yageo | RC0402FR-0718KL |  |  |  |  | 311-18.0KLRCT-ND | 603RC0402FR0718KL | 1987675 |  | 9239383
R8, R9, R16, R17 | 4 | 100k |  | RMCF0402JT100K | Stackpole Electronics | RMCF0402JT100K |  |  |  |  | RMCF0402JT100KDKR-ND
L1, L2, L3 | 3 | 2.2uH |  | DFE322512F-2R2M=P2 | Murata | DFE322512F-2R2M=P2 | TDK | TFM322512ALMA2R2MTAA |  |  | 445-TFM322512ALMA2R2MTAADKR-ND | 81DFE322512F2R2MP2 |  | 57AC6667 | 3490850 | C285758
D4, D5, D6, D7, D17, D28, D29 | 7 | 1N914 |  | 1N4148WS | Diotec | 1N4148WS | onsemi | 1N914BWS | Nexperia | BAS316Z | 1N914BWSDKR-ND | 5121N914BWS |  |  | 2453274RL
D8, D9 | 2 | 3.6V |  | BZT52C3V6S | Rectron | BZT52C3V6S | MCC | BZT52C3V6S-TP |  |  | BZT52C3V6S-TPMSCT-ND | 833BZT52C3V6STP
D0 | 1 | GREEN |  | LTST-C190GKT | Lite-On | LTST-C190GKT |  |  |  |  | 160-1183-2-ND | 859LTSTC190GKT | 6920975P
D1 | 1 | BLUE |  | LTST-C190TBKT | Lite-On | LTST-C190TBKT |  |  |  |  | 160-1646-1-ND | 859LTSTC190TBKT | 6920994P
D2 | 1 | GREEN |  | LTST-C190GKT | Lite-On | LTST-C190GKT |  |  |  |  | 160-1183-2-ND | 859LTSTC190GKT | 6920975P
D3 | 1 | BLUE |  | LTST-C190TBKT | Lite-On | LTST-C190TBKT |  |  |  |  | 160-1646-1-ND | 859LTSTC190TBKT | 6920994P
U1 | 1 | LFE5UM-85F-8BG381I |  | LFE5UM-85F-8BG381I | Lattice Semiconductor | LFE5UM-85F-8BG381I |  |  |  |  | LFE5UM-85F-8BG381I-ND | 842LFE5UM85F8BG381I
U2 | 1 | IS42S16320D-6BLI |  | IS42S16320D-6BLI | ISSI | IS42S16320D-6BLI |  |  |  |  | IS42S16320D-6BLI-ND | 870IS42S16320D6BLI
U3, U4, U5 | 3 | TLV62569DBV |  | TLV62569DBVR | Texas Instruments | TLV62569DBVR |  |  |  |  | 296-47360-2-ND | 595TLV62569DBVR |  |  | 3121687
U10 | 1 | W25Q128JVSIM |  | W25Q128JVSIM | Winbond | W25Q128JVSIM |  |  |  |  | W25Q128JVSIM-ND | 454W25Q128JVSIM | 1882648P
Y1 | 1 | FO3HSCBE25.0-T1 |  | FO3HSCBE25.0-T1 | Fox Electronics | FO3HSCBE25.0-T1 |  |  |  |  | 631-1432-1-ND | ASE25.000MHZLCT
SW1, SW2 | 2 | SW_Push |  | R-667903 | Mitsumi | R-667903 |  |  |  |  | 2508-R-667903CT-ND
J1, J2 | 2 | DF40C-100DP-0.4V(51) |  | 798-DF40C100DP0.4V51 | Hirose | DF40C-100DP-0.4V(51) |  |  |  |  | H11614DKR-ND | 798DF40C100DP0.4V51 |  |  | 2427678

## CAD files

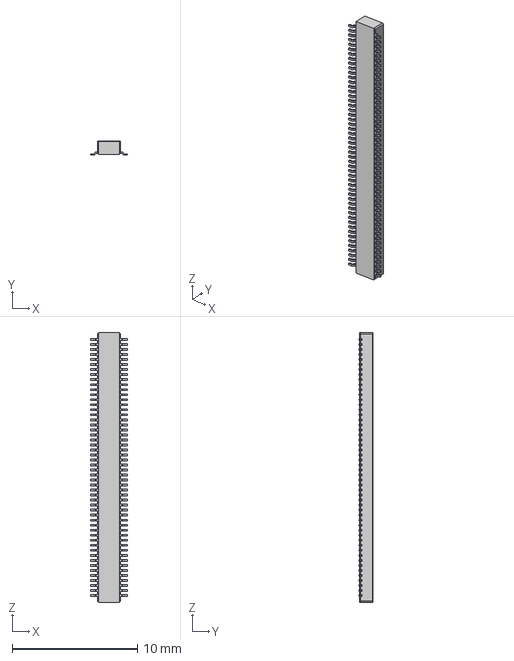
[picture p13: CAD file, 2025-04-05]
footprints/connectors/3D/DF40C-100DP.stp
2.97 x 1.14 x 21.5 mm

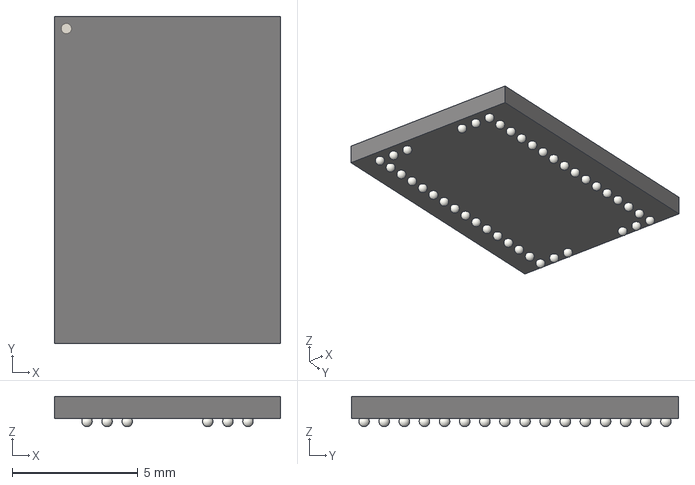
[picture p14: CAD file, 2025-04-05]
footprints/ddr3/AS4C256M16D3/3D/BGA-96_9.0x13.0mm_Layout2x3x16_P0.8mm.step
9.00 x 13.0 x 1.21 mm

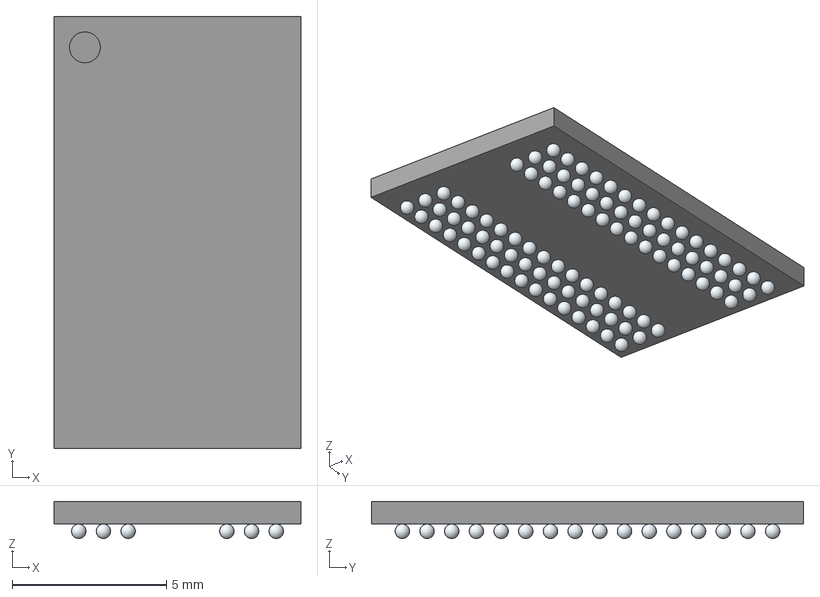
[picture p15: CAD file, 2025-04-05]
footprints/ddr3/MT41K256M16TW-107_P/3D/MT41K256M16TW-107_P.stp
8.00 x 14.0 x 1.20 mm
A1
A2
A3
A7
A8
A9
B1
B2
B3
B7
B8
B9
C1
C2
C3
C7
C8
C9
D1
D2
D3
D7
D8
D9
E1
E2
E3
E7
E8
E9
F1
F2
F3
F7
F8
F9
G1
G2
G3
G7
G8
G9
H1
H2
H3
H7
H8
H9
J1
J2
J3
J7
J8
J9
K1
K2
K3
K7
K8
K9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

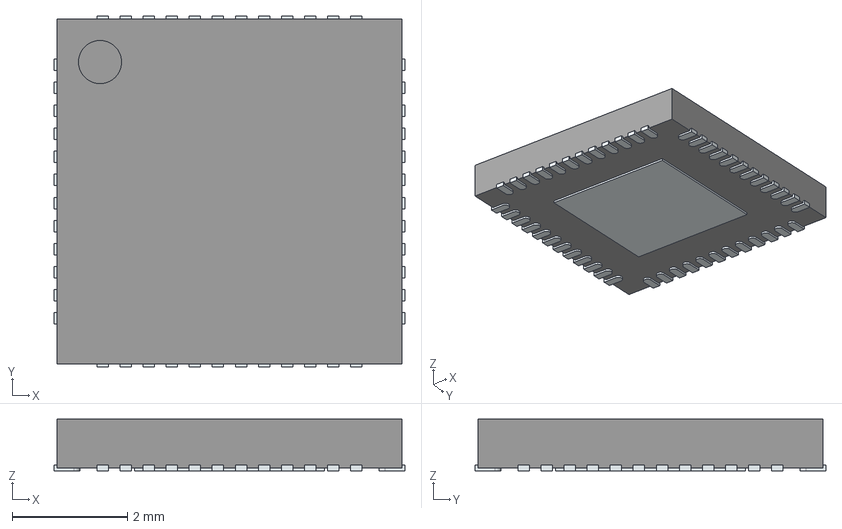
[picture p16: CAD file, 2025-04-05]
footprints/network/VSC8530XMW-04/3D/VSC8530XMW-04.stp
6.10 x 6.10 x 0.9 mm
ThermalPin
PinsArrayLR
PinsArrayTB

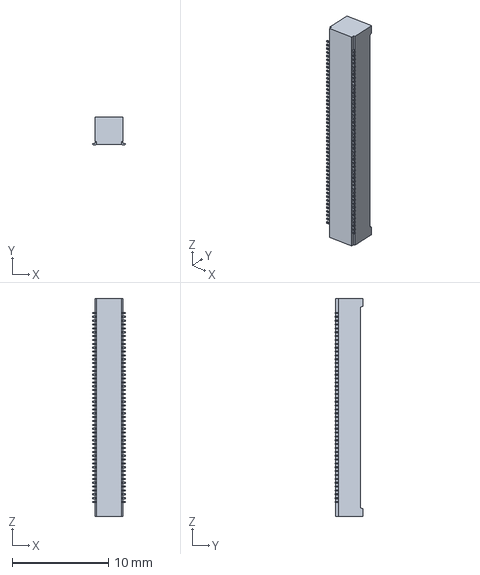
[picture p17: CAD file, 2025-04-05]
footprints/connectors/3D/DF40HC(3.0)-100DS-0.4V.stp
3.38 x 2.90 x 22.6 mm

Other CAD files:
footprints/network/VSC8530XMW-04/3D/VSC8530XMW-04.stl

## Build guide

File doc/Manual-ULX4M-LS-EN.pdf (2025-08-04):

MANUAL FOR THE USE OF MODULAR

# ULX4M-LS

1

SADRŽAJ

ULX4M-LS (Lattice+SDRAM)

### 1. Introduction 1.1. Main parts 1.2. Programing options 1.3. Periferije 1.4. Electrical and mechanical specifications 1.5. Power 2. ULX4M-LS description and instructions 3. ULX4M-LS on the internet 3.1. ULX4M-LS design files 3.2. ULX4M-LS v2 schematics

### 3.3. ULX4M-LS v2 LPF

### 4. JTAG over GPIO 5. DFU bootloader for ULX4M-LS 5.1. Usage 5.2. Write Protecting Bootloader 6. Chat and support 6.1. Instructions for safe use

2

# ULX4M-LS (Lattice+SDRAM)

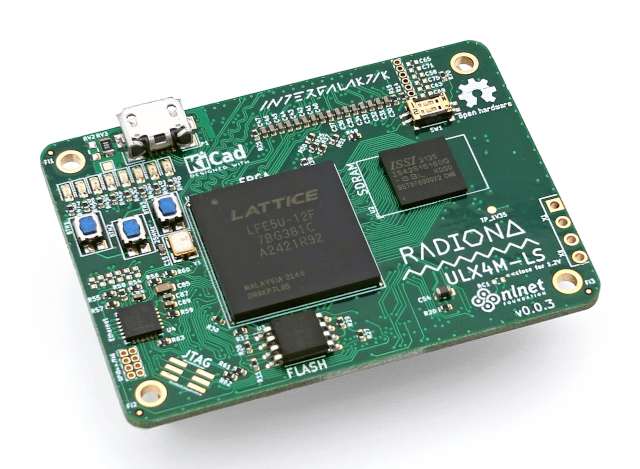
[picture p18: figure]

Slika 1. ULX4M-LS modular plate

FPGA: Lattice ECP5 LFE5U-12F-6BG381C (12/25/45/85K LUT)

3

# 1.Introduction

ULX4M-LS (Lattice + SDRAM) is a system on a module (SoM) board that can be used on CM4 compatible base board or as a standalone board.

## 1.1. Main parts

- LFE5U-12F-6BG381C
- IS42S16160G-7BL 32 MB SDRAM
- W25Q128JVSIM NOR Flash spiFlash, 3V, 128M-bit, 4Kb Uniform Sector
- Ethernet - LAN8720A

## 1.2. Programing options

External JTAG programming connector

JTAG connected to GPIO (programming with FTDI or ESP32)

USB (bootloader)

## 1.3. Periferije

- 2 lane CSI camera port CAM0 and CAM1
- 2 lane DSI display port DISP0 (fake differential)
- DISP0 pins connected to DISP1
- True differential GPDI video output
- Fake differential GPDI video output

4

- 4 bit SD card connection
- GPIOs
- 3 Buttons
- 2 DIP SW
- 8 LEDs

## 1.4. Electrical and mechanical specifications

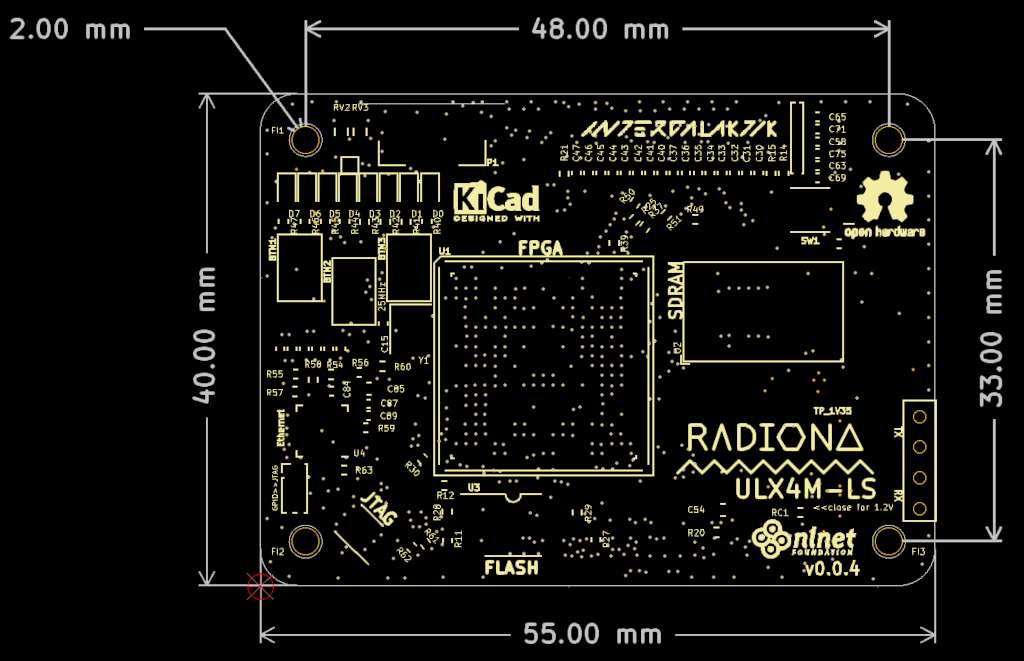
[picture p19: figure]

Slika 2. Electrical and mechanical specifications

## 1.5. Power

ULX4M requires at least 500mA to function safely. A 5V power supply can be provided over a USB port or over GPIO. 3.3V OUTPUT from ULX3S can handle up to 1A if appropriate input power is used.

5

# 2.ULX4M-LS description and instructions

On this version SD_CARD is also connected to GPIO pins, so we can share it with ESP32 as on ULX3S.

On this version FPGA JTAG pins are connected to some GPIO pins so you will not be able to use them as GPIOs, but you can access JTAG over GPIO.

If a Waveshare IO board is used it can be powered only from USB-C.

If you are using a Raspberry IO board then you will need 12V DC input as micro USB does not have 5V connected. There is one wire hack that can provide 5V from USB to the board. If this hack is used USB HOST will not work as it will disable HUB chip.

6

# 3.ULX4M-LS on the internet

## 3.1. ULX4M-LS design files

https://github.com/intergalaktik/ulx4m/tree/ulx4m-ls

## 3.2. ULX4M-LS v2 schematics

https://github.com/intergalaktik/ulx4m/blob/ulx4m-ls/doc/schematics.pdf

## 3.3. ULX4M-LS v2 LPF

https://github.com/intergalaktik/ulx4m/blob/ulx4m-ls/doc/constraints/prototype/ulx4m_ls_v003.lpf

7

# 4.JTAG over GPIO

For using JTAG over GPIO we need to close 4 traces with jumpers.

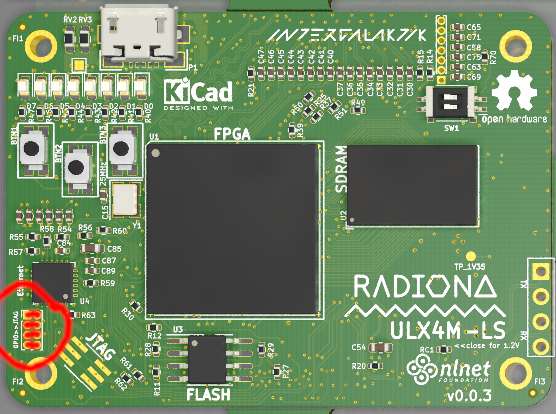
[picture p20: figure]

After connections JTAG is available on GPIO pins 12, 16, 20,21.

If JTAG over GPIO is used, avoid using those GPIOs in FPGA design as you will brick the board.

8

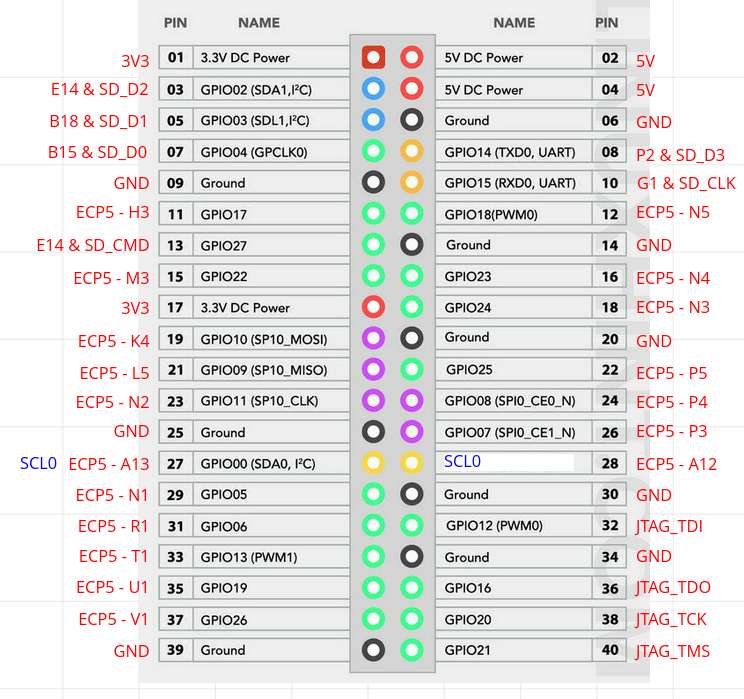
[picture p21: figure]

9

# 5.DFU bootloader for ULX4M-LS

USB DFU at US1 port for FPGA flashing. DFU is very fast.

Source is based on HAD2019 badge bootloader modified to ULX3S bootloader

Bootloader by default skips to the user's bitstream. If FLASH doesn't contain a valid user's bitstream, LEDs will blink because the bootloader is constantly restarting. This is normal.

To enter bootloader, hold BTN2 or set DIP SW1=ON and plug US1 In bootloader mode, LEDs 0-2 should be ON, other LEDs 3-7 OFF:

lsusb

Bus 001 Device 117: ID 1d50:614b OpenMoko, Inc. ULX4M-LS(DFU)

On linux, it's practical to add a udev rule which allows normal users members of "dialout" group to also run dfu-util, otherwise it should be run as root:

# file: /etc/udev/rules.d/80-fpga-dfu.rules

# this is for DFU 1d50:614b libusb access

ATTRS{idVendor}=="1d50", ATTRS{idProduct}=="614b", \

GROUP="dialout", MODE="666"

DFU is very fast, writes bitstream in a few seconds.

## 5.1. Usage

To upload a user bitstream, hold BTN2 or turn on DIP SW1 and plug USB. Here are some commandline examples:

dfu-util -a 0 -D blink.bit

openFPGALoader -b ulx3s-dfu blink.bit

10

To upgrade the bootloader, hold BTN1 and BTN2 and plug USB.

## 5.2. Write Protecting Bootloader

To prevent accidental overwriting, flash chips have options to protect a range of address space.

16MB ISSI and Winbond FLASH chips are supported

Different FLASH chips have standard/compatible commands for reading and writing but different commands for write protection. On ULX3S usual 16MB chips are ISSI IS25LP128 or Winbond W25Q128, both are supported by esp32ecp5 and work.

4MB ISSI FLASH chip is not supported.

ISSI IS25LP032 4MB is actually "supported", it has the same datasheet and commands as IS25LP128 but the onboard chip probably has some bug, it can't protect the address range where the bootloader is.

Protected range: first 2MB.

For this bootloader, the first 2MB (address 0 - 0x1FFFFF) should be write protected. It contains a bootloader bitstream and some data structure that can jump to the user's bitstream which starts from 0x200000.

FLASH protection applied here is based on non-OTP bits so it's reversible and protects from accidental overwriting with "fujprog", "esp32ecp5" and DFU bootloader itself. "fujprog" will segfault early, "esp32ecp5" will stop after first block verify, and the bootloader will upload data without error but content will not be written.

The current version of "openFPGALoader" will silently remove non-OTP write protection, overwrite the bootloader and leave the FLASH chip unprotected.

ISSI FLASH should be always safe and reversible. Winbond FLASH protection can set non-reversible OTP status register lock bits and in that case, there is no known way to remove protection.

11

# 6.Chat and support

Discord chanel

- https://discord.gg/qwMUk6W (problems/question/general chat)

## 6.1. Instructions for safe use

This product shall be connected to a computer/laptop USB port or external power supply rated at 5V DC with maximum current of 2A. Any external power supply used with ULX4M shall comply with relevant regulations and standards applicable in the country of intended use. This product should be operated in a well ventilated environment and should not be covered.

This product should be placed on a stable, flat, non-conductive surface in use and should not be contacted by conductive items. The connection of unapproved devices to any receptacle may affect compliance or results in damage to the unit and invalidate the warranty. Do not expose it to water, moisture or place on a conductive surface whilst in operation Do not expose it to heat from any source; ULX4M is designed for reliable operation at normal ambient room temperatures.

Take care whilst handling to avoid mechanical or electrical damage to the printed circuit board and connectors. Avoid handling ULX4M while it is powered. Only handled by the edges to minimize the risk of electrostatic discharge damage. All peripherals used with ULX4M should comply with relevant standards for the country of use and be marked accordingly to ensure that safety and performance requirements are met. ULX4M requires at least 500mA to function safely.

12

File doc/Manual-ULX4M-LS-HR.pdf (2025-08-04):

PRIRU NIK ZA KORIŠTENJE MODULARSKIH PLO ICA Č | Č

# ULX4M-LS

1

SADRŽAJ

ULX4M-LS (Lattice+SDRAM)

### 1. Uvod 1.1. Glavni dijelovi 1.2. Mogućnost programiranja 1.3. Periferije 1.4. Električne i mehaničke specifikacije 1.5. Snaga

### 2. ULX4M-LS opis i upute

### 3. ULX4M-LS na internetu 3.1. ULX4M-LS design files 3.2. ULX4M-LS v2 schematics

### 3.3. ULX4M-LS v2 LPF

### 4. JTAG preko GPIO 5. DFU pokretački program za ULX4M 5.1. Korištenje 5.2. Bootloader za zaštitu od pisanja

### 6. Chat i podrška

### 6.1. Upute za sigurnosnu upotrebu

2

# ULX4M-LS (Lattice+SDRAM)


Slika 1. ULX4M-LS modular

FPGA: Lattice ECP5 LFE5U-12F-6BG381C (12/25/45/85K LUT)

3

# 1.Uvod

ULX4M-LS (Lattice + SDRAM) je sustav na ploči modula (SoM) koji se može koristiti na CM4 kompatibilnoj osnovnoj ploči ili kao samostalna ploča.

## 1.1. Glavni dijelovi

- LFE5U-12F-6BG381C
- IS42S16160G-7BL 32 MB SDRAM
- W25Q128JVSIM NOR Flash spiFlash, 3V, 128M-bit, 4Kb Uniform Sector
- Ethernet - LAN8720A

## 1.2. Mogućnost programiranja

Vanjski JTAG konektor za programiranje, JTAG spojen na GPIO (programiranje s FTDI ili ESP32) i USB (bootloader).

## 1.3. Periferije

- Priključak CSI kamere s 2 trake CAM0 i CAM1
- 2 traka DSI zaslonski priključak DISP0 (lažni diferencijal)
- DISP0 pinovi spojeni na DISP1
- Pravi diferencijalni GPDI video izlaz
- Lažni diferencijalni GPDI video izlaz
- 4-bitni priključak za SD karticu
- GPIO-ovi

4

- 3 gumba
- 2 DIP SW
- 8 LED dioda

Dostupno samo ako se koristi ECP5 SerDes čip.

## 1.4. Električne i mehaničke specifikacije


Slika 2. Električne i mehaničke specifikacije

## 1.5. Snaga

ULX4M zahtijeva najmanje 500 mA za siguran rad. Napajanje od 5V može se osigurati preko USB priključka ili preko GPIO. 3,3V IZLAZ iz ULX3S može podnijeti do 1 A ako se koristi odgovarajuća ulazna snaga.

5

# 2.ULX4M-LS opis i upute

Na ovoj verziji SD_CARD je također spojena na GPIO pinove, tako da je možemo dijeliti s ESP32 kao na ULX3S.

Na ovoj verziji FPGA JTAG pinovi su spojeni na neke GPIO pinove, tako da ih se neće moći koristiti kao GPIO-e, ali se može pristupiti JTAG-u preko GPIO-a.

Ako se koristi Waveshare IO ploča, može se napajati samo iz USB-C priključka.

Ako se koriste Raspberry IO ploču, potreban je 12V DC ulaz jer micro USB nema spojenih 5V. Postoji jedan žičani hack koji može osigurati 5V s USB-a na ploču. Ako se koristi ovaj hack, USB HOST neće raditi jer će onemogućiti HUB čip.

6

# 3.ULX4M-LS na internetu

## 3.1. ULX4M-LS design files

https://github.com/intergalaktik/ulx4m/tree/ulx4m-ls

## 3.2. ULX4M-LS v2 schematics

https://github.com/intergalaktik/ulx4m/blob/ulx4m-ls/doc/schematics.pdf

## 3.3. ULX4M-LS v2 LPF

https://github.com/intergalaktik/ulx4m/blob/ulx4m-ls/doc/constraints/prototype/ulx4m_ls_v003.lpf

7

# 4.JTAG preko GPIO

Za korištenje JTAG preko GPIO treba zatvoriti 4 linije.


Nakon toga JTAG je dostupan na GPIO pinovima 12, 16, 20,21.

Ako se koristi JTAG preko GPIO nikako se u FPGA dizajnu ne smiju koristiti navedeni GPIO pinovi!

8


9

# 5.DFU pokretački program za ULX4M

USB DFU na US1 portu za FPGA flash. DFU je vrlo brz.

Izvor se temelji na HAD2019 badge bootloaderu modificiranom u ULX3S bootloader

Bootloader prema zadanim postavkama preskače na korisnikov bitstream.

Ako FLASH ne sadrži važeći korisnički bitstream, LED će blinkati jer se bootloader stalno ponovno pokreće.

Za ulazak u bootloader, držite BTN2 ili postavite DIP SW1=ON i priključite US1. U bootloader modu, LED 0-2 bi trebali biti UKLJUČENI, ostali LED 3-7 ISKLJUČENI:

lsusb

Bus 001 Device 117: ID 1d50:614b OpenMoko, Inc. ULX4M-LD(DFU)

Na linuxu je praktično dodati udev pravilo koje omogućuje normalnim korisnicima članovima "dialout" grupe da također pokreću dfu-util, inače ga treba pokrenuti kao root:

# file: /etc/udev/rules.d/80-fpga-dfu.rules

# this is for DFU 1d50:614b libusb access

ATTRS{idVendor}=="1d50", ATTRS{idProduct}=="614b", \

GROUP="dialout", MODE="666"

DFU je vrlo brz, zapisuje bitstream u nekoliko sekundi.

## 5.1. Korištenje

Za prijenos korisničkog bitstreama, držite BTN2 ili uključite DIP SW1 i uključite USB. Evo nekoliko primjera naredbenog retka:

openFPGALoader -b ulx3s-dfu blink.bit

ili

10 dfu-util -a 0 -D blink.bit

Da biste izašli iz pokretačkog programa i izvršili korisnički bitstream, upotrijebite naredbu DFU:
dfu-util -a 0 -e

Za nadogradnju bootloadera, držite BTN1 i BTN2 i uključite USB.

## 5.2. Bootloader za zaštitu od pisanja

Kako bi se spriječilo slučajno prepisivanje, flash čipovi imaju opcije za zaštitu raspona adresnog prostora.

Podržani su 16MB ISSI i Winbond FLASH čipovi.

Različiti FLASH čipovi imaju standardne/kompatibilne naredbe za čitanje i pisanje, ali različite naredbe za zaštitu od pisanja. Na ULX3S uobičajeni čipovi od 16 MB su ISSI IS25LP128 ili Winbond W25Q128, oba podržava esp32ecp5 i rade.

4MB ISSI FLASH čip nije podržan.

ISSI IS25LP032 4MB je zapravo "podržan", ima istu podatkovnu tablicu i naredbe kao IS25LP128, ali ugrađeni čip vjerojatno ima neku grešku, ne može zaštititi raspon adresa gdje je bootloader.

Zaštićeni raspon: prvih 2 MB.

Za ovaj bootloader, prvih 2MB (adresa 0 - 0x1FFFFF) treba biti zaštićeno od pisanja. Sadrži bitstream bootloadera i neke podatkovne strukture koje mogu skočiti na korisnički bitstream koji počinje od 0x200000.

Od onoga što štiti FLASH zaštita koja se ovdje primjenjuje temelji se na bitovima koji nisu OTP pa je reverzibilna i štiti od slučajnog prepisivanja s "fujprog", "esp32ecp5" i DFU bootloader.

11

# 6.Chat i podrška

Discord chanel

- https://discord.gg/qwMUk6W (problems/question/general chat)

## 6.1. Upute za sigurnosnu upotrebu

Ovaj proizvod mora biti spojen na USB priključak računala/prijenosnog računala ili vanjsko napajanje nazivno na 5 V DC s maksimalnom strujom od 2 A. Svako vanjsko napajanje koje se koristi s ULX4M mora biti u skladu s relevantnim propisima i standardima primjenjivim u zemlji namjeravane uporabe. Ovaj proizvod treba raditi u dobro prozračenom okruženju i ne smije biti pokriven.

Ovaj proizvod treba staviti na stabilnu, ravnu, nevidljivu površinu tijekom uporabe i ne smiju ga dodirivati vodljivi predmeti. Spajanje neodobrenih uređaja na bilo koju utičnicu može utjecati na sukladnost ili rezultirati oštećenjem jedinice i poništiti jamstvo. Nemojte ga izlagati vodi, vlazi niti ga stavljati na vodljivu površinu dok radi. Nemojte ga izlagati toplini iz bilo kojeg izvora; ULX4M je dizajniran za pouzdan rad pri normalnim sobnim temperaturama.

Pazite tijekom rukovanja kako biste izbjegli mehanička ili električna oštećenja tiskane ploče i konektora. Izbjegavajte rukovanje ULX4M dok je napajan. Držite samo za rubove kako biste smanjili rizik od oštećenja elektrostatičkim pražnjenjem. Svi periferni uređaji koji se koriste s ULX4M trebaju biti u skladu s relevantnim standardima za zemlju upotrebe i biti odgovarajuće označeni kako bi se osiguralo ispunjavanje sigurnosnih i radnih zahtjeva. ULX4M zahtijeva najmanje 500 mA za siguran rad.

12

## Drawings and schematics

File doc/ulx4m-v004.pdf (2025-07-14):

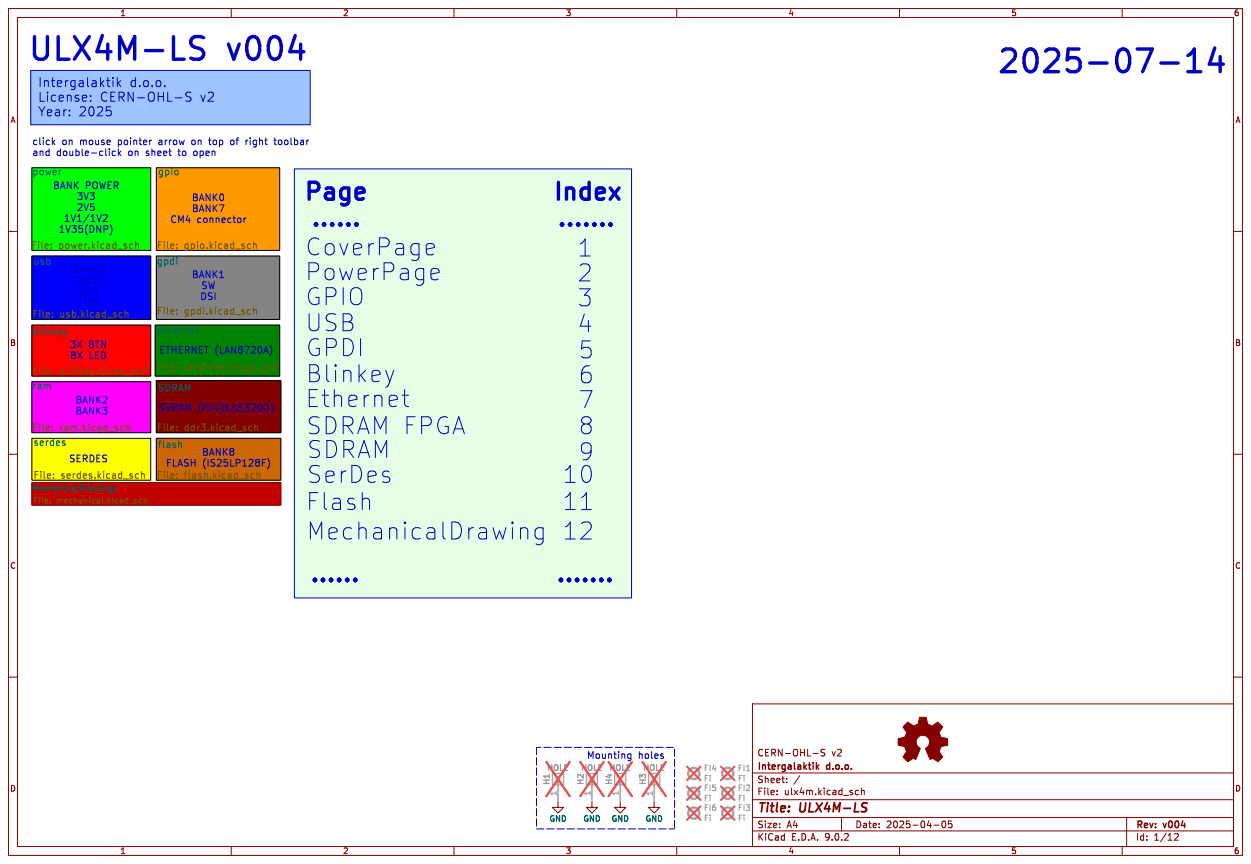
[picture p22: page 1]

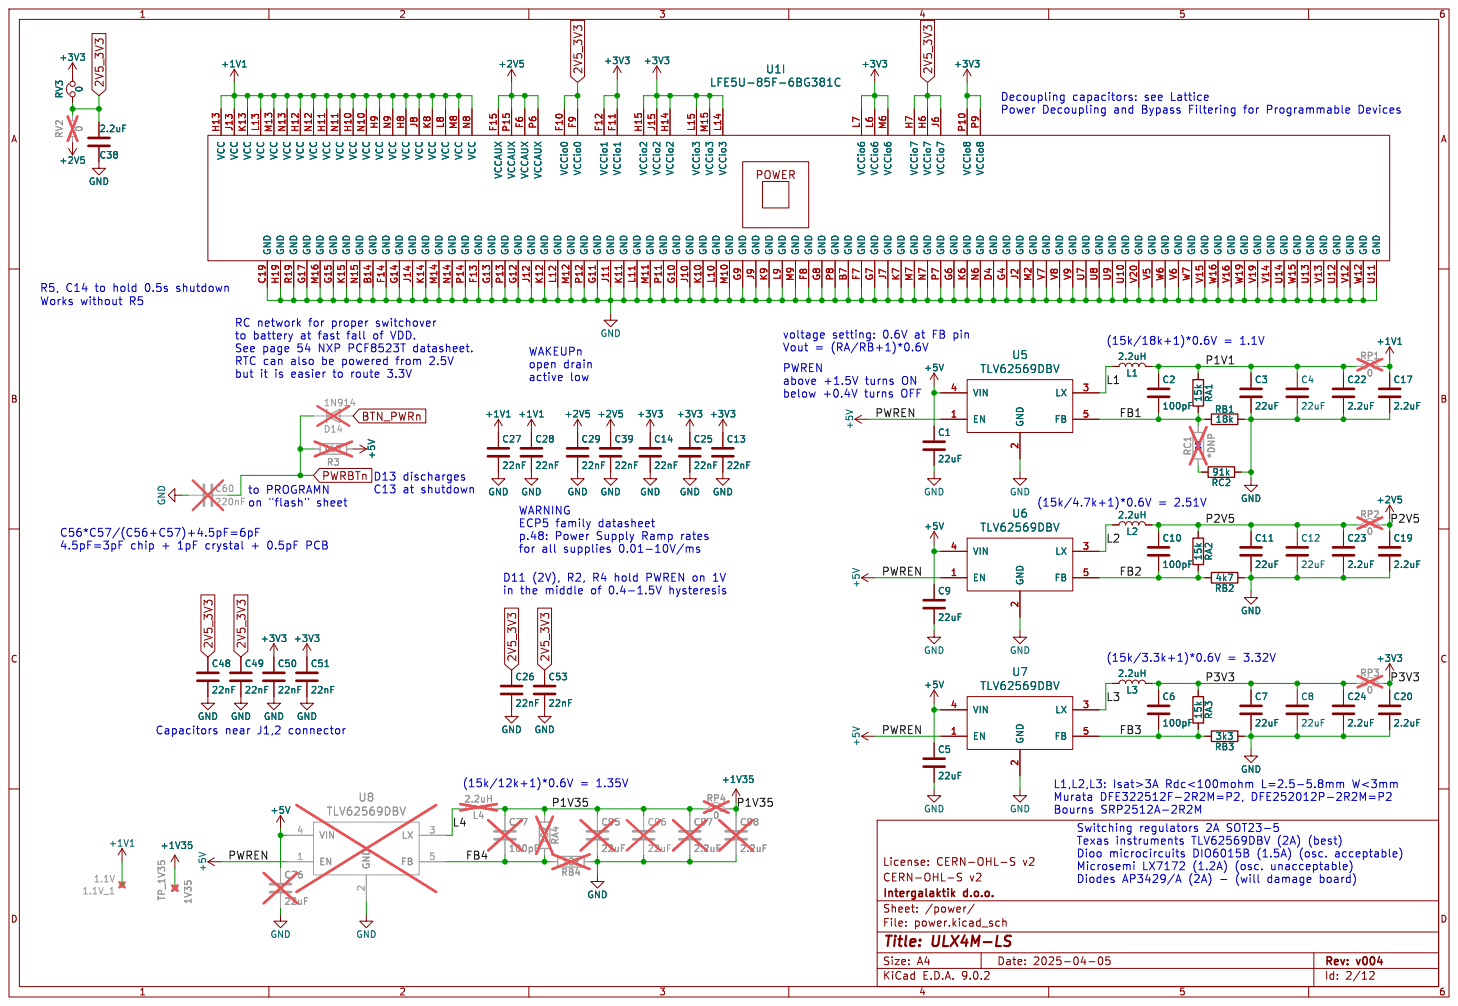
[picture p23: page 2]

R5, C14 to hold 0.5s shutdown RC network for proper switchover

to battery at fast fall of VDD. See page 54 NXP PCF8523T datasheet. RTC can also be powered from 2.5V

voltage setting: 0.6V at FB pin Vout = (RA/RB+1)*0.6V

ECP5 family datasheet p.48: Power Supply Ramp rates

for all supplies 0.01-10V/ms D11 (2V), R2, R4 hold PWREN on 1V

File: power.kicad_sch Sheet: /power/
Id: 2/12 Title: ULX4M-LS

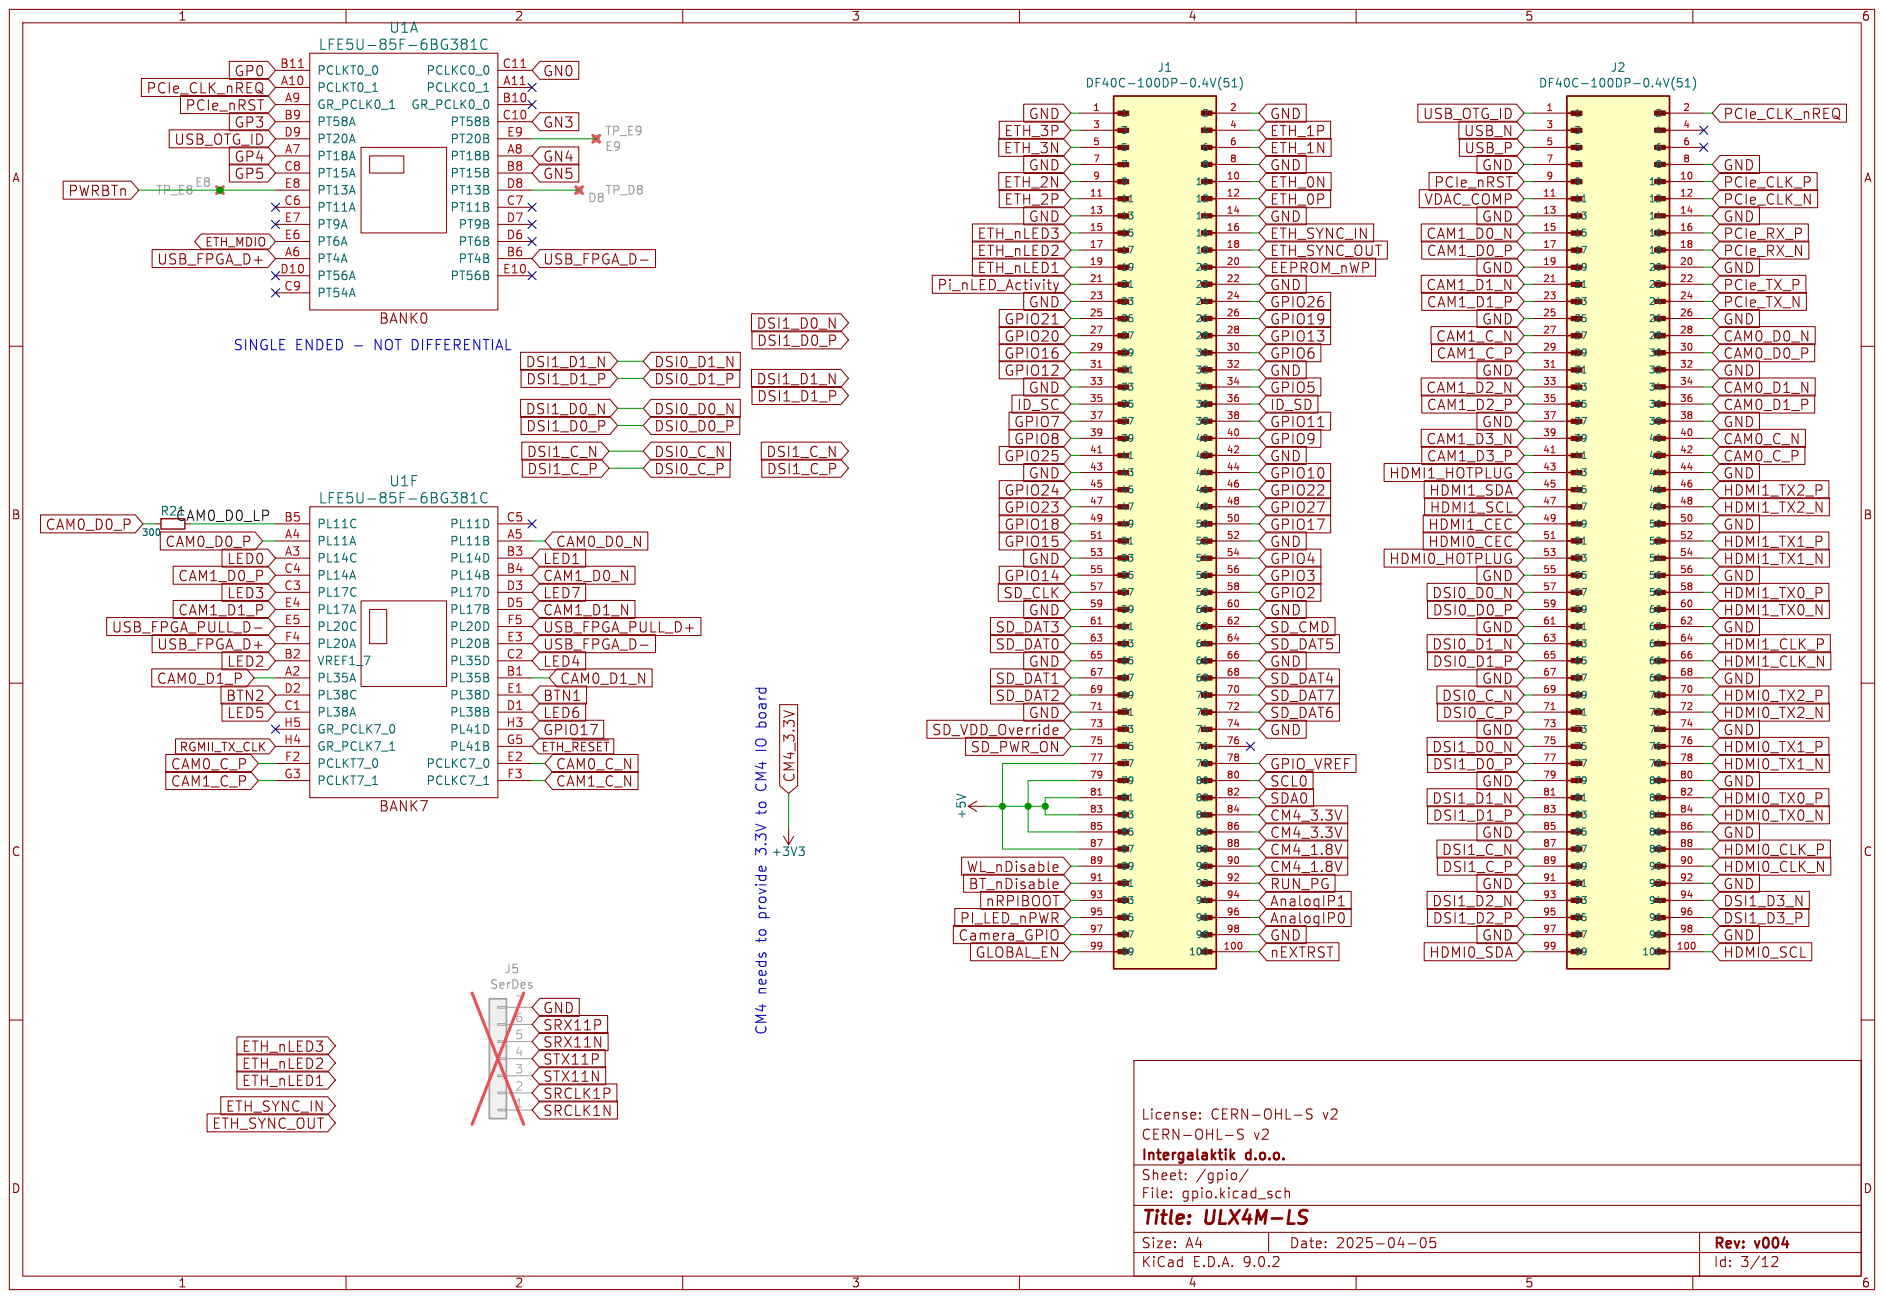
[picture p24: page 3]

File: gpio.kicad_sch Sheet: /gpio/
Id: 3/12 Title: ULX4M-LS

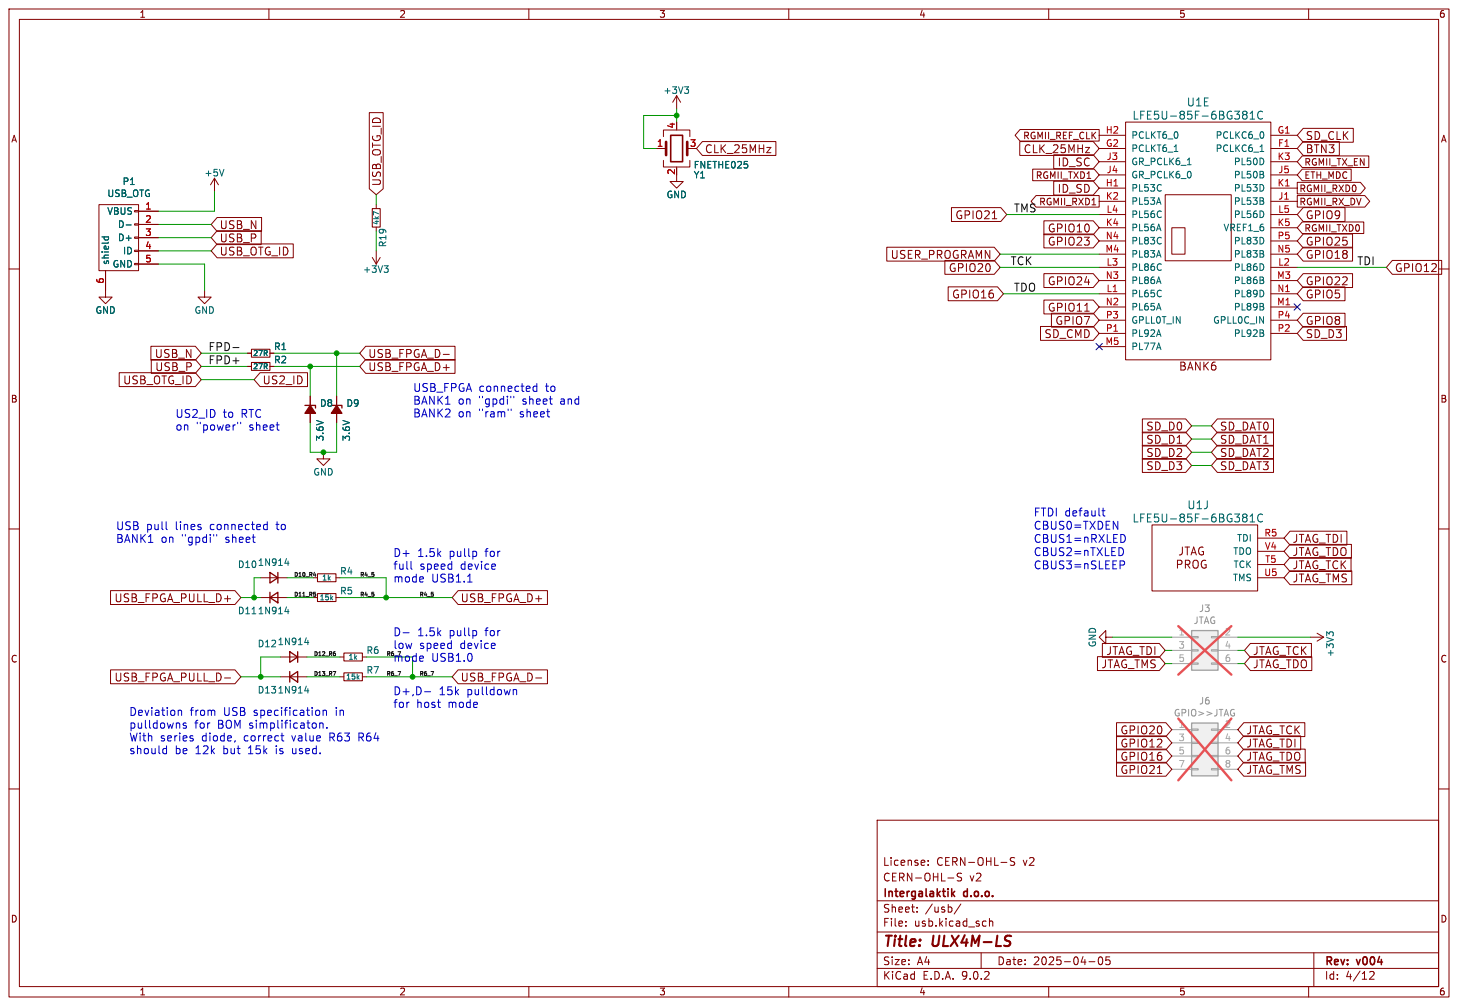
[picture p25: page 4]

D- 1.5k pullp for
low speed device mode USB1.0

File: usb.kicad_sch Sheet: /usb/
Id: 4/12 Title: ULX4M-LS

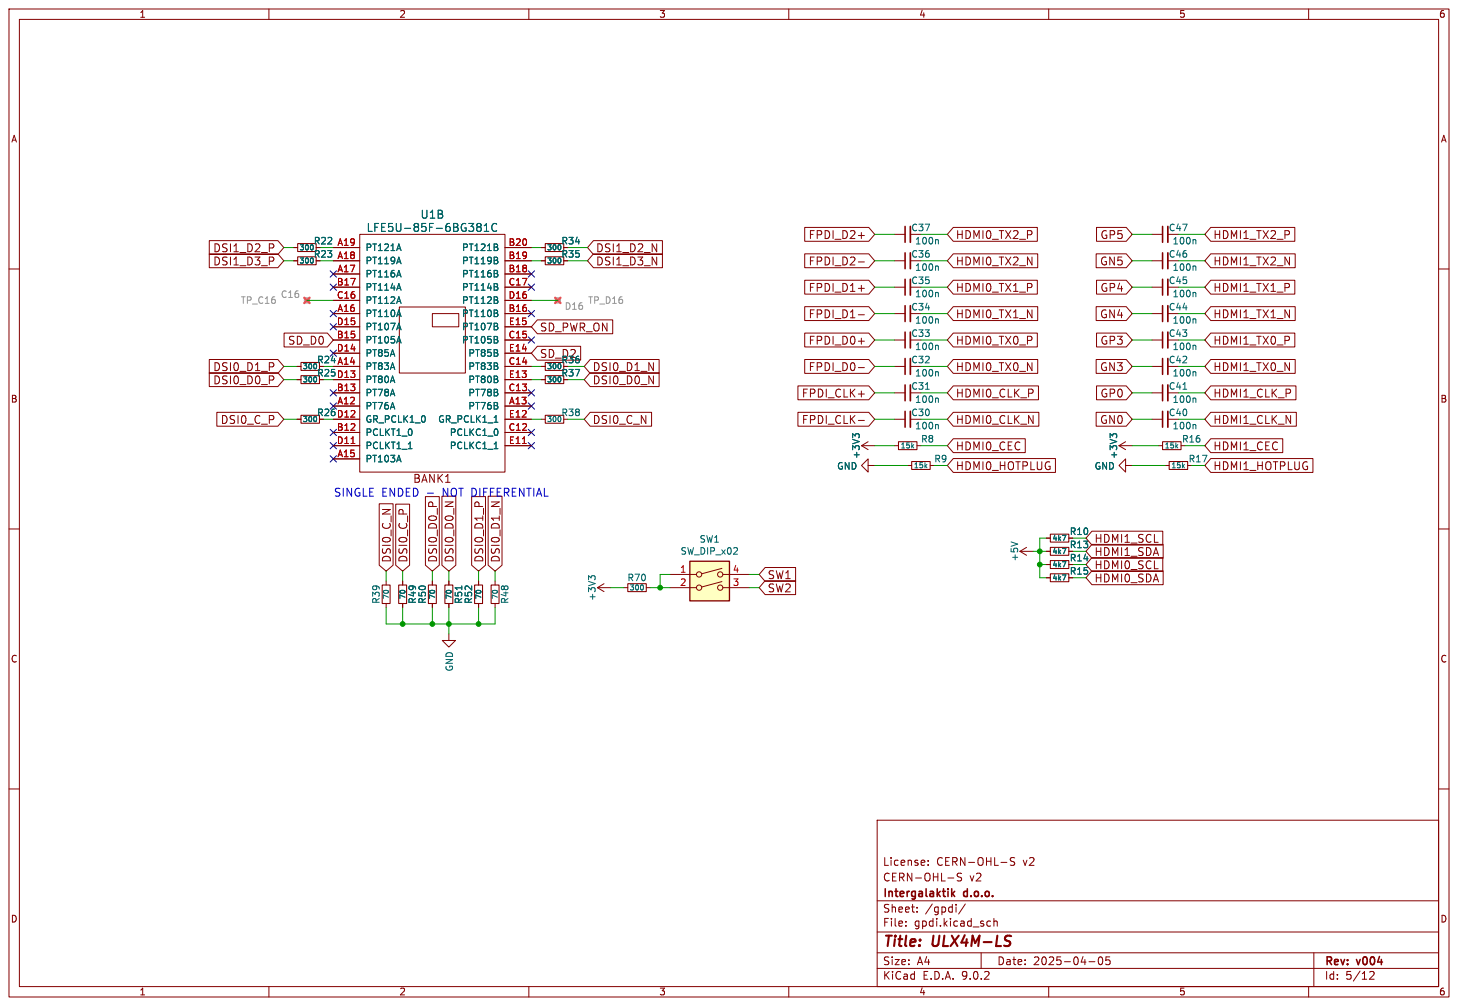
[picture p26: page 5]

SINGLE ENDED - NOT DIFFERENTIAL U1B

File: gpdi.kicad_sch Sheet: /gpdi/
Id: 5/12 Title: ULX4M-LS

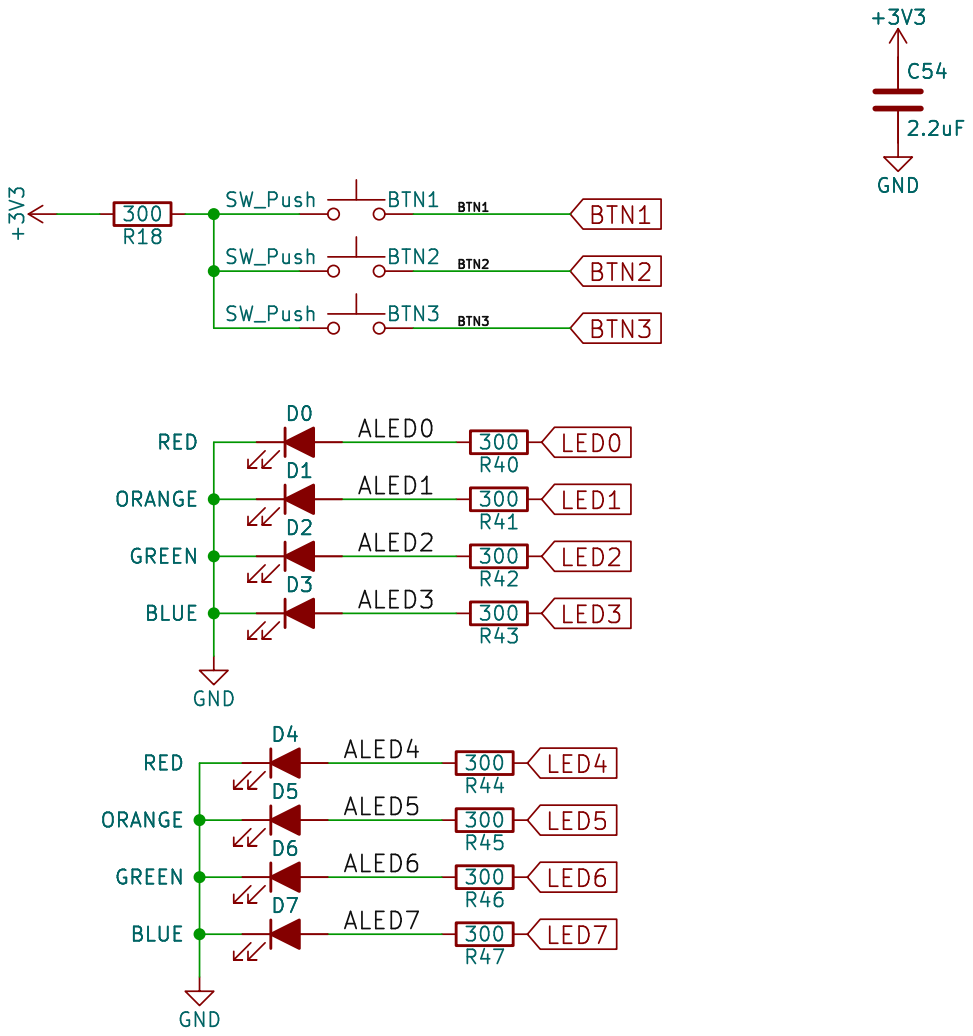
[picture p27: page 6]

File: blinkey.kicad_sch Sheet: /blinkey/
Id: 6/12 Title: ULX4M-LS

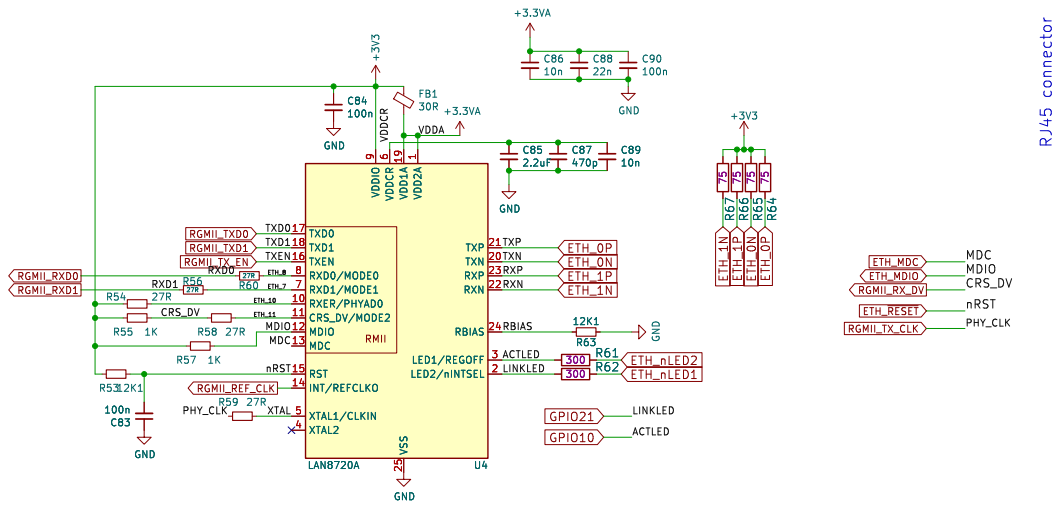
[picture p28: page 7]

1 TXP 21 TXN 20 RXP 23 RXN 22 RBIAS 24

File: ethernet.kicad_sch Sheet: /ethernet/
Id: 7/12 Title: ULX4M-LS

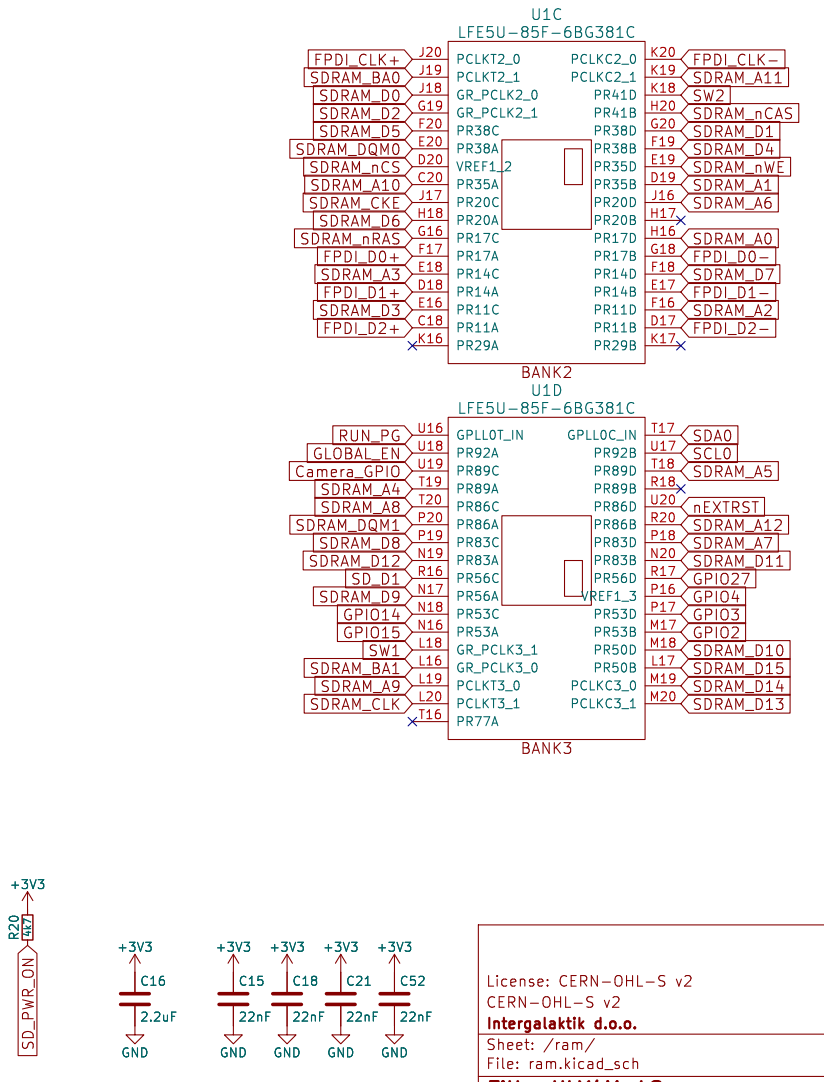
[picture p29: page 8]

File: ram.kicad_sch Sheet: /ram/
Id: 8/12 Title: ULX4M-LS

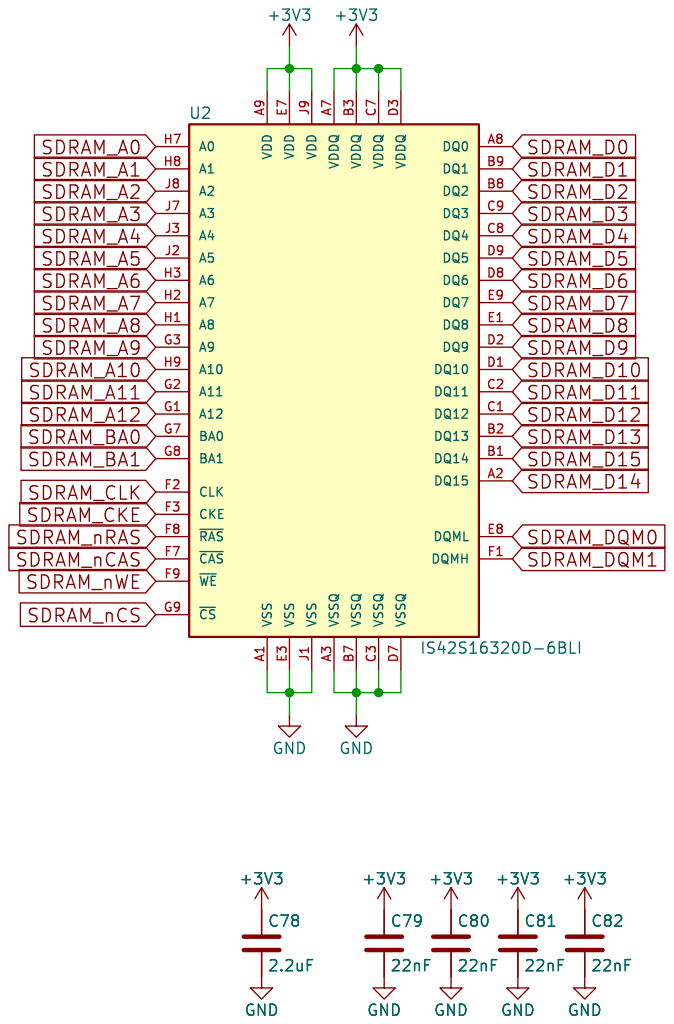
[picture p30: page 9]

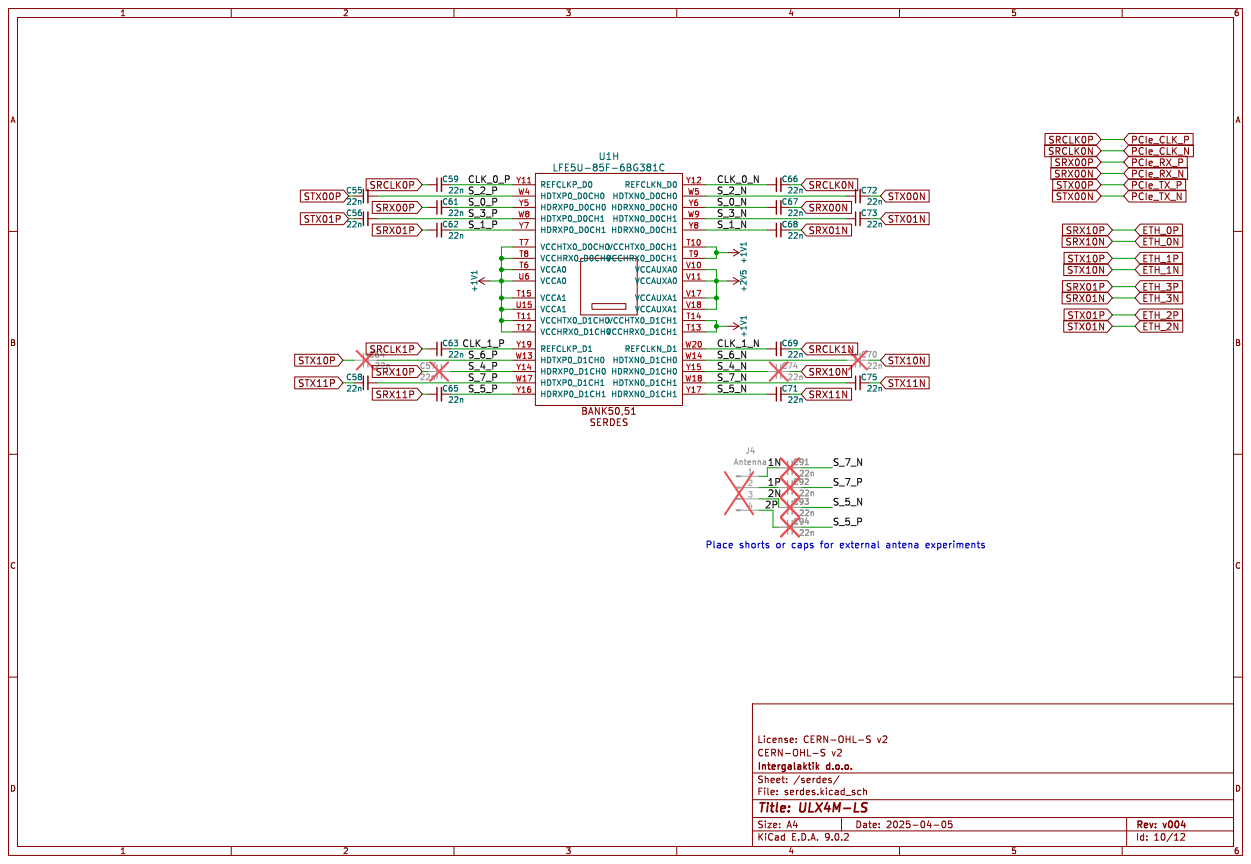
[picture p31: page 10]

File: serdes.kicad_sch Sheet: /serdes/
Id: 10/12 Title: ULX4M-LS

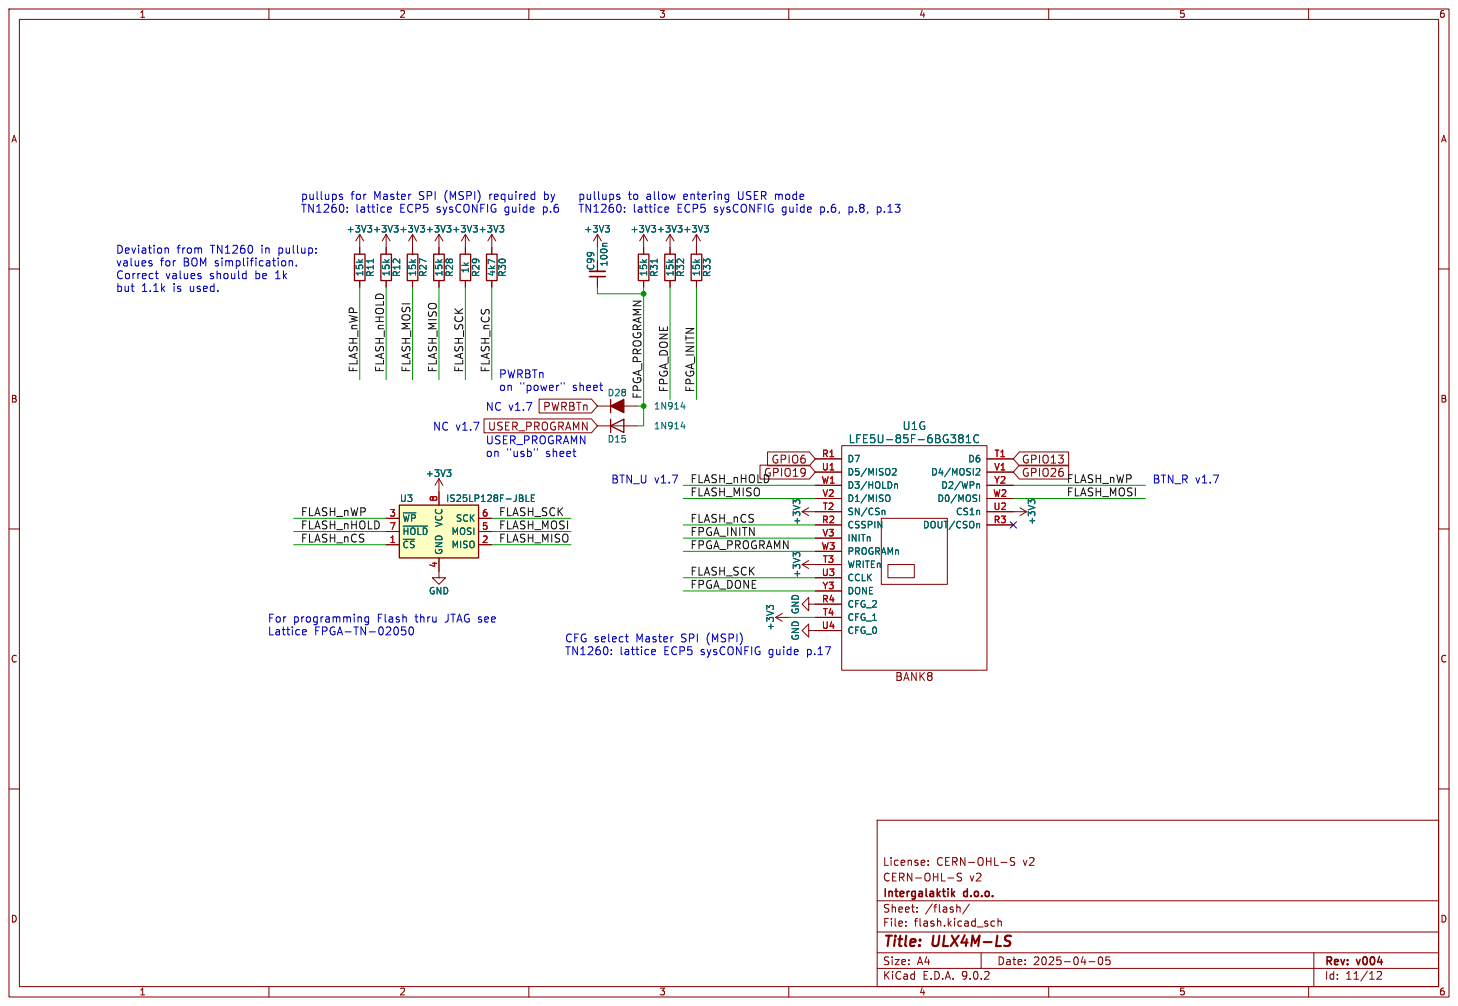
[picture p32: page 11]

4 SCK 6 MOSI 5 MISO 2 U3 IS25LP128F-JBLE D15

File: flash.kicad_sch Sheet: /flash/
Id: 11/12 Title: ULX4M-LS

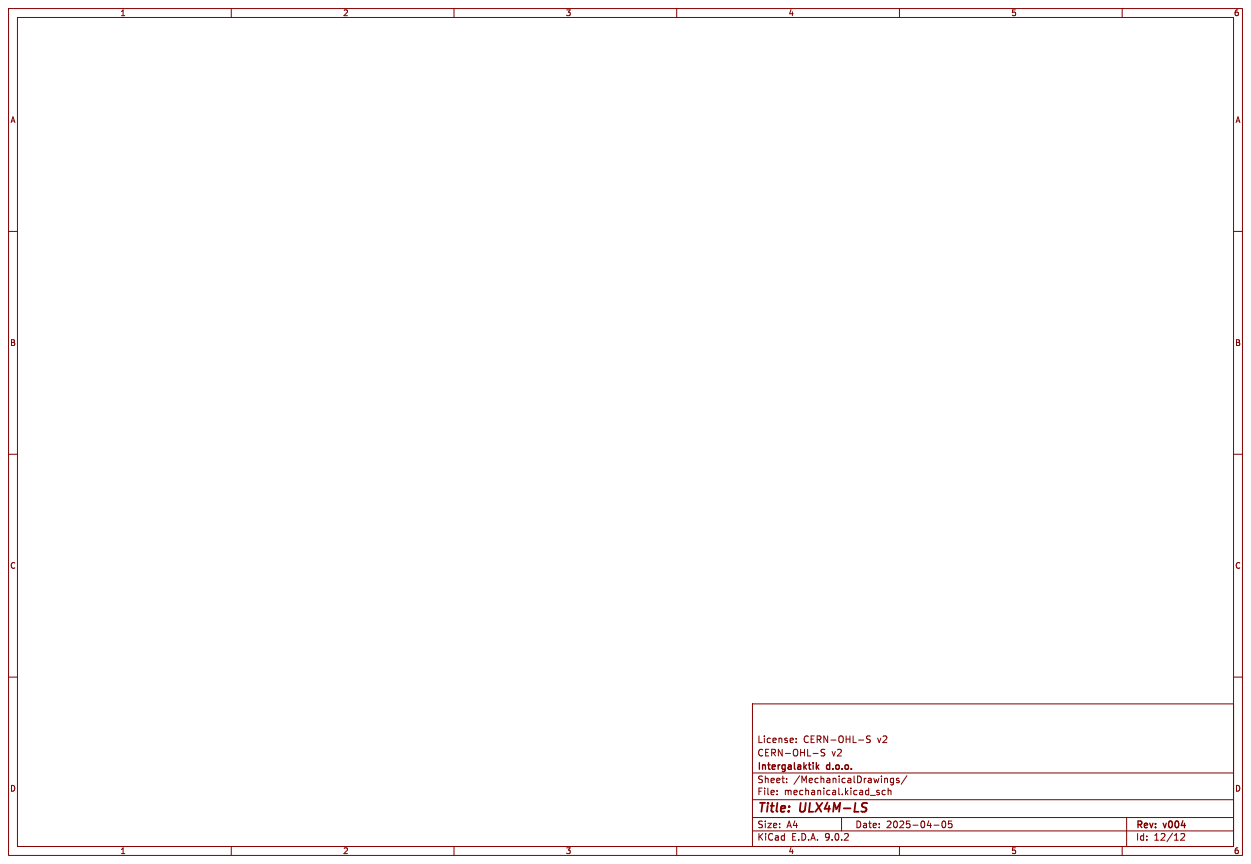
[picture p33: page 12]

File: mechanical.kicad_sch Sheet: /MechanicalDrawings/
Id: 12/12 Title: ULX4M-LS

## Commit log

2025-04-05 Initial ULX4M-LS-V004
    [1-click-bom.tsv, BGA-96_9.0x13.0mm_Layout2x3x16_P0.8mm.step, DF40C-100DP.stp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]
2025-04-05 Updating schematics
    [blinkey.kicad_sch, ddr3.kicad_sch, ethernet.kicad_sch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]
2025-04-09 Adding BOM - adding DNP to some components
    [ULX4M-LS-V004-BOM.xlsx, blinkey.kicad_sch, ddr3.kicad_sch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]
2025-04-09 switching to latest KiKit
2025-04-15 Adding frame to all boards

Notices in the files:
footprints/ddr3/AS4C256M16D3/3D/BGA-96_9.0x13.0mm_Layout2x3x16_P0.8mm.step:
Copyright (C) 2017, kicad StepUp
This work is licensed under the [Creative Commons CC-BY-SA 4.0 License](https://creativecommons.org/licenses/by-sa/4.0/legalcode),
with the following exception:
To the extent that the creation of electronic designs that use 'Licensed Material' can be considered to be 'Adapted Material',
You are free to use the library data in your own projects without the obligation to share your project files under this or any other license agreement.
